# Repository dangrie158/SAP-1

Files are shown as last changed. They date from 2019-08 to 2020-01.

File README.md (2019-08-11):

# SAP-1 (Simple as Possible)

A simple 8-bit micro-processor using mostly discrete logic chips.

This project is mostly based on the [8-bit Breadboard computer](https://eater.net/8bit) by [Ben Eater](https://eater.net)

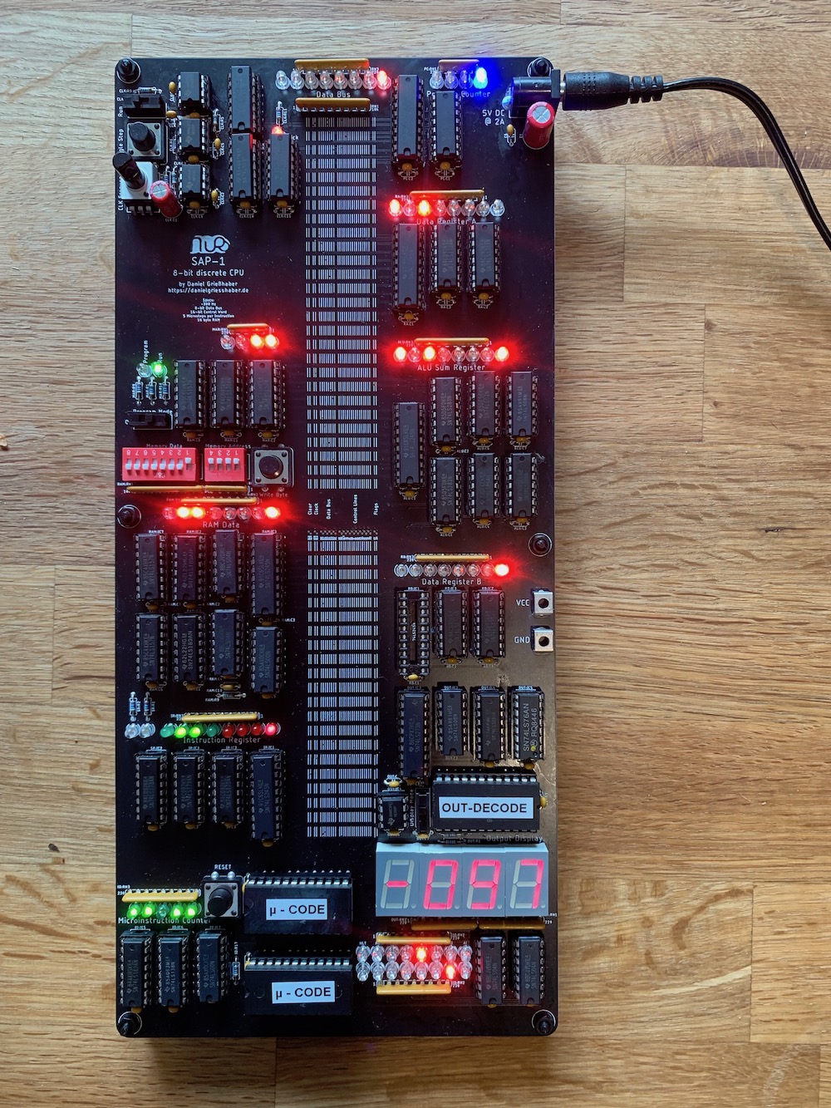
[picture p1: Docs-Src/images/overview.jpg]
Image of the Processor Board


## Banner Specs

- ~400 Hz Clock
- 8-bit Data Bus
- 16-bit Control Word
- 5 Microsteps per Instruction
- 16 byte RAM

## Documentation

Check the projects [Pages](https://dangrie158.github.io/SAP-1/) for the documentation of the ISA and Hardware modules.

## Submodules:

- Clock with adjustable frequency and single-step button
- 2 8-bit Data Registers (A & B)
- ALU implementing sum and difference between Registers A & B, carry and zero flag
- Flag Register to save the ALU flags between instructions
- 4-bit Instruction Counter with load (jump)
- Output module to display a byte as positive decimal or 2s-complement with data latch
- Random Access Memory with 16 Bytes for instructions and data
- 4-bit Memory Address Register to address the 16 bytes of RAM
- 8-bit Instruction Register with the upper nibble representing the opcode, the lower nibble can be used for instruction parameters
- Instruction Decoder to run the microcode of the 16 different instructions with 5 microinstuctions each. Uses a 16-bit control word to control the other modules

## Project Structure

| Files | Description |
|---|---|
| ```Board/Board.*``` | Autodesk Eagle project woth the Schematic and a fully routed Boardlayout |
| ```Board/Board_*.zip``` | precreated Gerbers for Production |
| ```Board/BOM.xlsx``` | a BOM with [Mouser](https://www.mouser.com) partnumbers |
| ```Spec/ISA.py``` | a Python module that defines and documents the Instruction Set Architecture of the Processor. |
| ```Spec/lut_microcode.py``` | script to create the microcode LUT binary for the ID EEPROMS. Uses ```ISA.py``` |
| ```Spec/lut_outputdecoder.py``` | script to create the LUT binary for the output decode EEPROM |
| ```LUTs/*.bin``` | precreated binaries for the EEPROMS |
| ```Example-Programs/*.s``` | Some Example Programs in SAP-1 assembly |
| ```Tools/sap-asm``` | Assembler for SAP-1 assembly listings. Outputs binaries or prints programming instructions. |
| ```Simulations/``` | [iCircuit](http://icircuitapp.com) simulation files for some parts of the architecture |

## Writing Code
The documentation has an extensive section on the [Instruction Set Architecture](https://dangrie158.github.io/SAP-1/isa.html) you can use to get started writing programs.

### Assembler:

In the ``Tools`` directory an assembler is available that can either output binary files or, if it detects stdout to be a TTY, prints programming instructions for you to manually program the RAM using the DIP-Switches.

```
$ cat Example-Programs/Counter.s 
.data:
0xF: 0x1

LDA 0xF
loop:
OUT
ADD 0xF
JMP loop

$ Tools/sap-asm Example-Programs/Counter.s
○○○○: ○○○●●●●●
○○○●: ●●●○○○○○
○○●○: ○○●○●●●●
○○●●: ○●●○○○○●
●●●●: ○○○○○○○●

$ Tools/sap-asm Example-Programs/Counter.s | hexdump 
0000000 1f e0 2f 61 00 00 00 00 00 00 00 00 00 00 00 01
0000010
```

## Programming the EEPROM LUTs

The provided ```Makefile``` offers some convenient rules to create the LUTs and program them to an EEPROM.
To program the LUTs you can use an [Arduino based programmer](https://github.com/dangrie158/EEPROgraMmer)
with only 2 external chips (+EEPROM) which is the officially supported method using the 
[```eepro```](https://pypi.org/project/eepro/) CLI. 

However, you can also use any other programmer to flash the binary files created by the scripts.

If you want to use ```eepro```, make sure the package is installed

```bash
pip3 install -r requirements.txt
```

Then you can programm the needed 3 EEPROMS (1x Output Decoder, 2x Microcode) using 

```bash
make program_lut file=LUTs/microcode.bin        # < for the microcode EEPROMS
make program_lut file=LUTs/outputdecoder.bin    # < for the Output Decoder EEPROM
```

The rule makes sure the LUTs are created or updated if the creating script has changed since last creation.

If you want to use any other programmer, just run 

```bash
make luts
```

to create the binaries in the ```LUTs/``` directory.

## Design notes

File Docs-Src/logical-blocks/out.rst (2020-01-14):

====================
Output Display (OUT)
====================
The output display can load the contents of the databus and
display it as a decimal integer on the 4x 7-segment displays.

It supports the display of either a unsigned :math:`\left[ 0, 255\right]`
or 2s-complement signed :math:`\left[ -128, 127\right]` 8-bit value.

Mode of Operation
=================
The value to display is read from the databus and saved in a
`SN74LS273 <https://www.ti.com/lit/ds/symlink/sn54ls273-sp.pdf>`_
*octal d-type flip-flop* on a riding clock edge when the
:math:`LOAD` signal is active.
Due to the lack of an enable pin on the register IC, the load signal is
implemented by ANDing the :math:`CLK` and :math:`LOAD` signal.

BCD decoder
+++++++++++
The decoding of the binary display is implemented as a lookup table (LUT)
using a `28C16 <http://cva.stanford.edu/classes/cs99s/datasheets/at28c16.pdf>`_
*2K x 8-bit parallel EEPROM*.
This IC has 11 address pins :math:`A_0-A_{10}` of which the first 8 are used to
input the display-value.
The next 2 address bits are used to select the digit of the display currently
active.
This leaves the last address pin to select the display mode (unsigned or
signed) using :math:`\mathrm{OUT\colon S_3}`.

Digit multiplexing
++++++++++++++++++
Since the EEPROM decoder can only drive a single digit at any time with it's 8
output lines, the 4 digits need to be multiplexed.
This is done by sequentially driving the common-cathode pin of each digit low
while simultaneously setting the :math:`A_8` and :math:`A_9` address pins of
the EEPROM which in turn will drive the anodes of the selected display digit
to the apropriate value.

The binary digit select signal that drives the address lines is implemented
by a single `SN74LS76 <http://www.ti.com/lit/ds/symlink/sn54ls76a.pdf>`_
*dual J-K flip flop* IC to implement a 2 bit binary counter.
This counter is driven by an astable `LM555 <http://www.ti.com/lit/gpn/lm555>`_
oscillator that runs fast enough to cycle through the digits without
perceivable flickering:

.. math::

   {f}_{out} &= \frac{1.44}{\mathrm{OUT\colon R_1} + 2* \mathrm{OUT\colon R3}) * \mathrm{OUT\colon C_7}} \\
   {f}_{out} &= \frac{1.44}{201kΩ * 10nF} \\
   {f}_{out} &= ~716Hz

.. math::

   {f}_{multiplex} &= \frac{{f}_{out}}{4} \\
   {f}_{multiplex} &= ~179Hz

The bianry coded digit select signal is then decoded using a
`SN74LS139 <http://www.ti.com/lit/ds/symlink/sn54ls139a-sp.pdf>`_
*2-line to 4-line decoder with active low outputs* to drive the cathodes.

LED Output Drive
++++++++++++++++
According to the `datasheet <http://cva.stanford.edu/classes/cs99s/datasheets/at28c16.pdf>`_
of the decoder EEPROM, the chip can drive :math:`10-20mA` with a
:math:`0.5 - 1.5V` drop in its output voltage.
This may be too big of a drop when combined with the :math:`220Ω` series
resistors when used for higher voltage drop LED displays (like blue or white).
If you have trouble with the output display being too dim or not lighting
up at all, replace the resistor networks :math:`\mathrm{RN}_1`
and :math:`\mathrm{RN}_2` with jumpers or choose a lower resistance network.

Schematic
=========
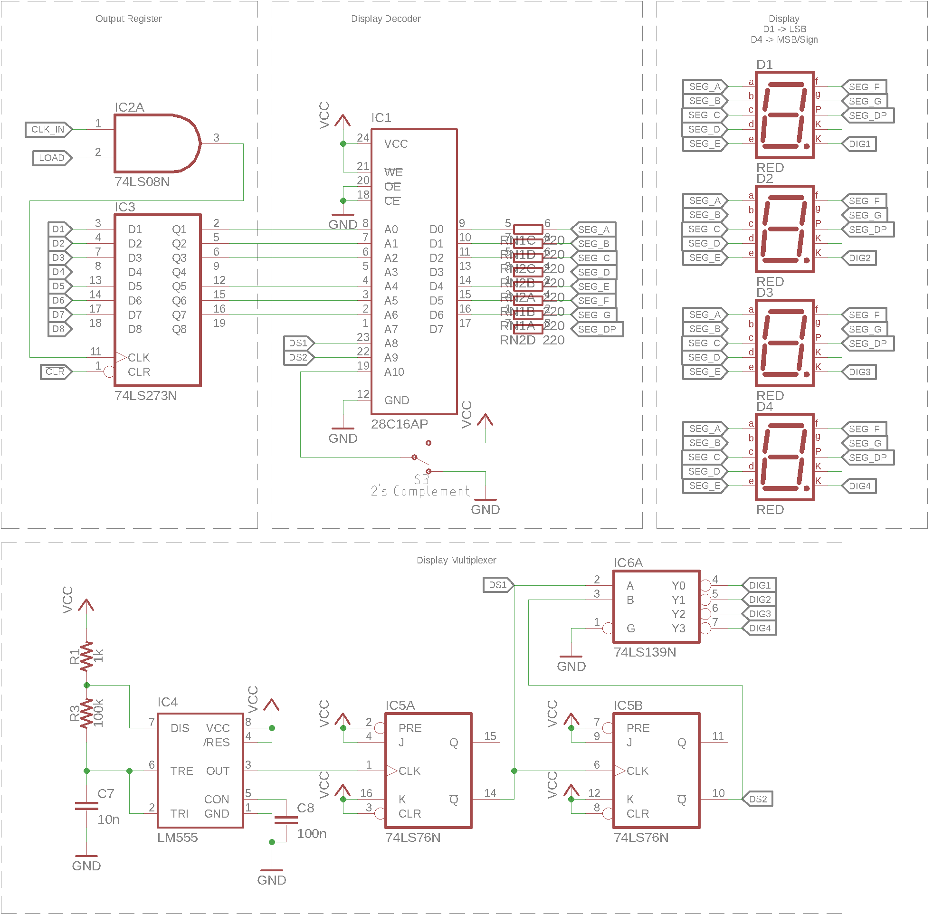
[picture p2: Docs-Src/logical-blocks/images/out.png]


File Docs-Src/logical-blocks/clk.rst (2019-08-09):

===========
Clock (CLK)
===========
The clock module is responsible for all time related coordination
between the seperate modules.

Mode of Operation
=================
The module has 2 outputs that feed into the other modules,
the **positive clock line** (:math:`CLK`) and its
**logical inverse** (:math:`\overline{CLK}`).
The :math:`\overline{CLK}` signal is always low when the clock signal is
high and vice-versa, this way the processor has 2 clock signals that are
on a 180° phase difference.

The source for the clock pulses is selectable via the **Source Select**
switch and can either be set to *run* mode or *single-step*.

*Run* mode
----------
In *run* mode, the clock signal is created by a 555 timer in astable
configuration. The dutycycle of the signal is 50%, while the frequency
can be set using a potentiometer.
The clock frequency is set by :math:`\mathrm{CLK\colon R_1}`,
:math:`\mathrm{CLK\colon R_2} + \mathrm{CLK\colon RV_2}` and
:math:`\mathrm{CLK\colon C_1}`:

.. math::

   {f}_{clk} &= \frac{1.44}{( \mathrm{CLK\colon R_1} + 2 * (\mathrm{CLK\colon R_2} + \mathrm{CLK\colon RV_2}) ) * \mathrm{CLK\colon C_1}} \\
   {f}_{clk} &= \frac{1.44}{( 1kΩ + 2*(1kΩ + [0, 100kΩ]) ) * 1µF} \\
   {f}_{clk} &= [480.0Hz, ~7.1Hz]

*Single-step* mode
------------------
In *single-step* mode, the positive clock signal is set by pressing the
**Single Step** button and cleared after releasing it.
Another 555 timer in monostable configuration is used to debounce
the button presses to avoid accidentaly creating multiple steps on a
single press.
The debounce time is set by the RC network consisting of
:math:`\mathrm{CLK\colon R_6}` and :math:`\mathrm{CLK\colon C_5}` and can be
calculated as:

.. math::

   T_o &= 1.1 * \mathrm{CLK\colon R_6} * \mathrm{CLK\colon C_5} \\
   T_o &= 1.1 * 100nF * 1kΩ \\
   T_o &= 110µS

Clock Source selection & Halt signal
------------------------------------
The actual output signal is a logical combination of the two 555 timer
outputs and the output of a third 555 in bistable mode.
This third 555 is used to debounce the signal of a single-pole
double-throw (SPDT) slide-switch.
The debouncing is neccessary because otherwise a switch bounce could
generate multiple clock ticks when switching modes while the 2 clock
signals have a different state.

In any way, a clock pulse is only output if the
**halt signal** (:math:`CLK_{HLT}`) is inactive.
This halt signal is part of the **control word (CW)** and can be used to
stop program execution.

.. math:: \mathrm{CLK} = \neg CLK_{HLT} \land ((\mathrm{CLK_{TICK}} \land \mathrm{CLK_{SEL}}) \lor (CLK_{STEP} \land \neg CLK_{SEL}))

Schematic
=================
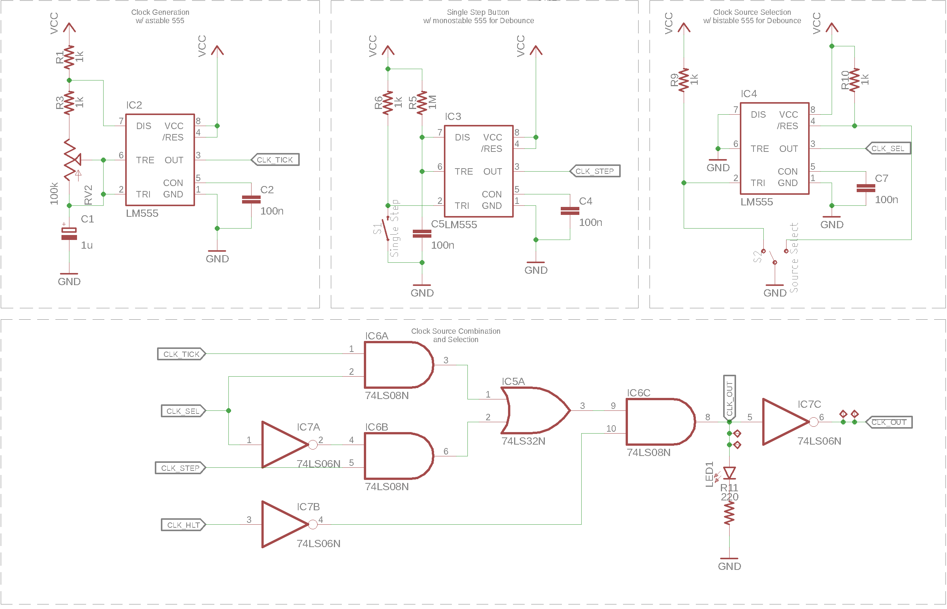
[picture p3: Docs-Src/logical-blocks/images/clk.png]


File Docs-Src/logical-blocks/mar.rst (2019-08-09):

=============================
Memory Address Register (MAR)
=============================
The memory address register stores the address of the data
the `RAM <ram.html>`_ module should be pointing at.

Mode of Operation
=================
The memory address register is very similar in its operation
principle to any of the `data registers <datareg.html>`_.

It uses the same `74LS173 <http://www.ti.com/lit/ds/symlink/sn54173.pdf>`_
*4-bit D-type registers*, however since it's output is not connected
to the databus but instead directly to the address pins of the RAM module,
no buffers are used at the output.

Instead a `74LS157 <http://www.ti.com/lit/ds/symlink/sn54157.pdf>`_
*quadruple 2-to-1 multiplexer* is used to select either the
register contents or a DIP switch array to set the address outputs.
The DIP switches can be used in **program mode** to set the address manually
while in **run mode** the address can be loaded as the lower 4 bits
of the data bus which represent the instruction data (ID) nibble of
an instruction (see the `ISA <../isa.html>`_ section for more detail).

To select the current mode of operation (run / program), the SPDT switch
**Program / Run** can be used.

Schematic
=========
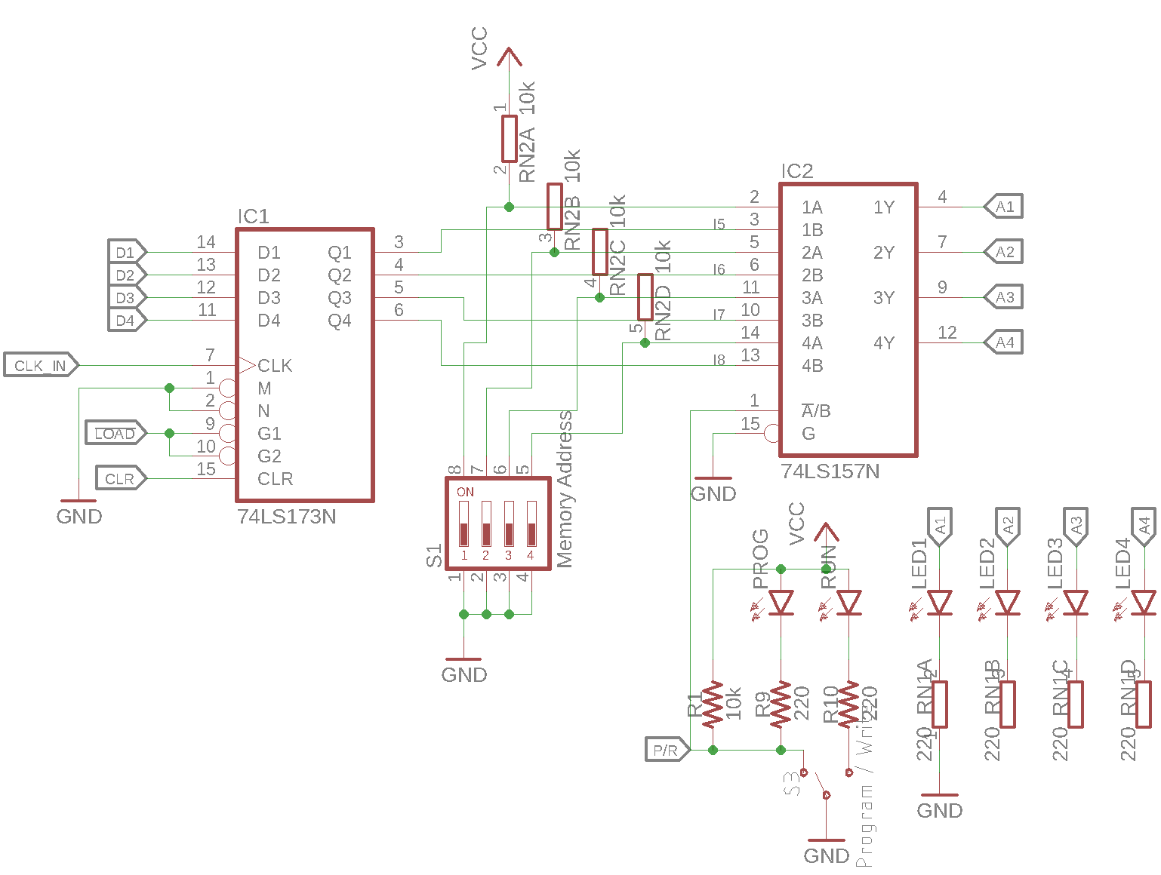
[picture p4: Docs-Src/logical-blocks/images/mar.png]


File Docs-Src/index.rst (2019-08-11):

.. SAP-1 Processor Architecture documentation master file, created by
   sphinx-quickstart on Wed Aug  7 08:08:43 2019.
   You can adapt this file completely to your liking, but it should at least
   contain the root `toctree` directive.

============================
SAP-1 Processor Architecture
============================

A simple 8-bit micro-processor using mostly discrete logic chips.

This project is mostly based on the `8-bit Breadboard computer <https://eater.net/8bit>`_
by `Ben Eater <https://eater.net>`_



   Overview of the assembled processor board running `Example-Programs/Counter.s`

Banner Specs
============

- ~400 Hz Clock
- 8-bit Data Bus
- 16-bit Control Word
- 5 Microsteps per Instruction
- 16 byte RAM

Source (I want to build my own)
===============================
Check the projects `Github <https://github.com/dangrie158/SAP-1/>`_ for all files neccecary.

Submodules
==========
- Clock with adjustable frequency and single-step button
- 2 8-bit Data Registers (A & B)
- ALU implementing sum and difference between Registers A & B,
    carry and zero flag
- Flag Register to save the ALU flags between instructions
- 4-bit Instruction Counter with load (jump)
- Output module to display a byte as positive decimal or
    2s-complement with data latch
- Random Access Memory with 16 Bytes for instructions and data
- 4-bit Memory Address Register to address the 16 bytes of RAM
- 8-bit Instruction Register with the upper nibble representing
    the opcode, the lower nibble can be used for instruction parameters
- Instruction Decoder to run the microcode of the 16 different instructions
    with 5 microinstuctions each. Uses a 16-bit control word to control the
    other modules

Writing Code
============
The documentation has an extensive section on the
`Instruction Set Architecture <https://dangrie158.github.io/SAP-1/isa.html>`_
you can use to get started writing programs.

Assembler
++++++++++
In the ``Tools`` directory an assembler is available that can
either output binary files or, if it detects stdout to be a TTY,
prints programming instructions for you to manually program the RAM
using the DIP-Switches.

.. code:: bash

    $ cat Example-Programs/Counter.s
    .data:
    0xF: 0x1

    LDA 0xF
    loop:
    OUT
    ADD 0xF
    JMP loop

    $ Tools/sap-asm Example-Programs/Counter.s
    ○○○○: ○○○●●●●●
    ○○○●: ●●●○○○○○
    ○○●○: ○○●○●●●●
    ○○●●: ○●●○○○○●
    ●●●●: ○○○○○○○●

    $ Tools/sap-asm Example-Programs/Counter.s | hexdump
    0000000 1f e0 2f 61 00 00 00 00 00 00 00 00 00 00 00 01
    0000010

Programming the EEPROM LUTs
===========================

The provided ``Makefile`` offers some convenient rules to
create the LUTs and program them to an EEPROM.
To program the LUTs you can use an
`Arduino based programmer <https://github.com/dangrie158/EEPROgraMmer>`_
with only 2 external chips (+EEPROM) which is the officially
supported method using the `eepro <https://pypi.org/project/eepro/>`_
CLI.

However, you can also use any other programmer to flash
the binary files created by the scripts.

If you want to use ``eepro``, make sure the package is installed

.. code:: bash

    pip3 install -r requirements.txt

Then you can programm the needed 3 EEPROMS (1x Output Decoder,
2x Microcode) using:

.. code:: bash

    make program_lut file=LUTs/microcode.bin     # < for the microcode EEPROMS
    make program_lut file=LUTs/outputdecoder.bin # < for the Out Decoder EEPROM

The rule makes sure the LUTs are created or updated if
the creating script has changed since last creation.

If you want to use any other programmer, just run

.. code:: bash

    make luts

to create the binaries in the ``LUTs/`` directory.

.. toctree::
   :maxdepth: 3
   :caption: Contents:

   isa
   block-diagram

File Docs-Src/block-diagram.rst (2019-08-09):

===============
Hardware Blocks
===============
The SAP-1 Processor can logically be grouped into the following
submodules.

.. toctree::
   :maxdepth: 1

   logical-blocks/clk
   Data Register A <logical-blocks/datareg>
   Data Register B <logical-blocks/datareg>
   Instruction Register <logical-blocks/datareg>
   logical-blocks/alu
   logical-blocks/ram
   logical-blocks/mar
   logical-blocks/pc
   logical-blocks/out
   logical-blocks/id
   logical-blocks/sr

The individual modules communicate over the 8-bit Data Bus and
are controlled by the control lines in the Control Word.
Other than that, the only shared signals between modules are the
global clock (CLK and its inverse !CLK), and the clear signal (CLR and !CLR).

The block diagram shows how the modules are connected together.
The 8-bit bus in the middle is the databus, while the blue line
on the outside is the control word with 16 control lines.

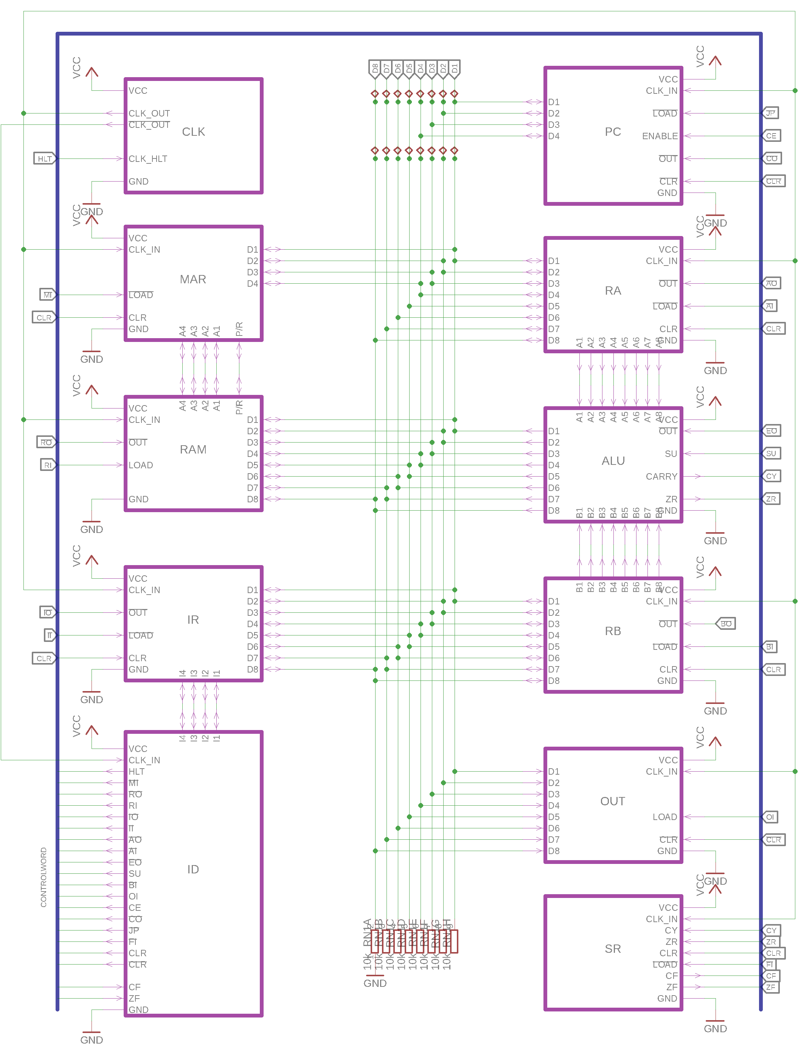
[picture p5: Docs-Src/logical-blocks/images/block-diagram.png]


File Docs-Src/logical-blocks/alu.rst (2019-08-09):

===========================
Arithmetic Logic Unit (ALU)
===========================
The ALU enables the Processor to perform simple arithmetic operations.
In fact, it only can perform the addition or substraction of the values
in the two data registers RA and RB:

.. math::
   \mathrm{ALU_{OUT}} &= \mathrm{RA} + \mathrm{RB} \quad \mathrm{or}\\
   \mathrm{ALU_{OUT}} &= \mathrm{RA} - \mathrm{RB}

Mode of Operation
=================

Addition
--------
The ALU uses 2 `74LS283 <http://www.ti.com/lit/ds/symlink/sn74ls283.pdf>`_
*4-bit binary adders with carry*.
The **carry output** (:math:`\mathrm{ALU\colon C_4}`) of
:math:`\mathrm{ALU\colon IC_1}` is connected to the **carry input**
(:math:`\mathrm{ALU\colon C_0}`) of :math:`\mathrm{ALU\colon IC_2}`,
thus a carry after bit 4 is propagated to the second nibble of the result.
The inputs A and B of the ICs are connected directly to the outputs
of the 74LS173 registers of RA and (through XOR gates) RB instead of
the DB.
For addition, the **substract line** :math:`\mathrm{SU}` line is low, thus
the XOR gates output the same value as the input from RB.
To only drive the DB lines when the result of the computation is needed,
another 74LS245 is used as tristate buffer, enabling the display of the
result on :math:`\mathrm{ALU\colon LED_{1-8}}` without driving the DB.

Substraction
------------
For substraction of RA and RB, the :math:`\mathrm{SU}` signal is active,
thus the output of the XOR gates is always the *logical inverse* of the input
from RB.
Thus the second byte into the 8-bit adder is the *1s complement* of RB.
To calculate a `2s complement <https://en.wikipedia.org/wiki/Two%27s_complement>`_
result however, the :math:`\mathrm{SU}` signal also drives the
:math:`\mathrm{ALU\colon C_0}` input of :math:`\mathrm{ALU\colon IC_1}`,
effectivley adding 1 to the result.

Flags
-----
The *carry signal* :math:`\mathrm{CY}` can be read directly from the
:math:`\mathrm{ALU\colon C_4}` pin of the second nibble adder
:math:`\mathrm{ALU\colon IC_2}`.

For the zero flag signal :math:`\mathrm{ZR}`, all output bits are NORed
together.
Since there are no 8-input NOR gates available (at least in the commonly
available 74LS series logic family), a quad 2-input NOR gate
(`74LS02 <http://www.ti.com/lit/ds/symlink/sn74ls02.pdf>`_) is used to
NOR every 2 bits together, then each of the outputs is ANDed together using
a quad 2-input AND gate (`74LS02 <http://www.ti.com/lit/ds/symlink/sn74ls02.pdf>`_)
until only a single signal is left that will be active high when all ALU
output bits are cleared.

Schematic
=========
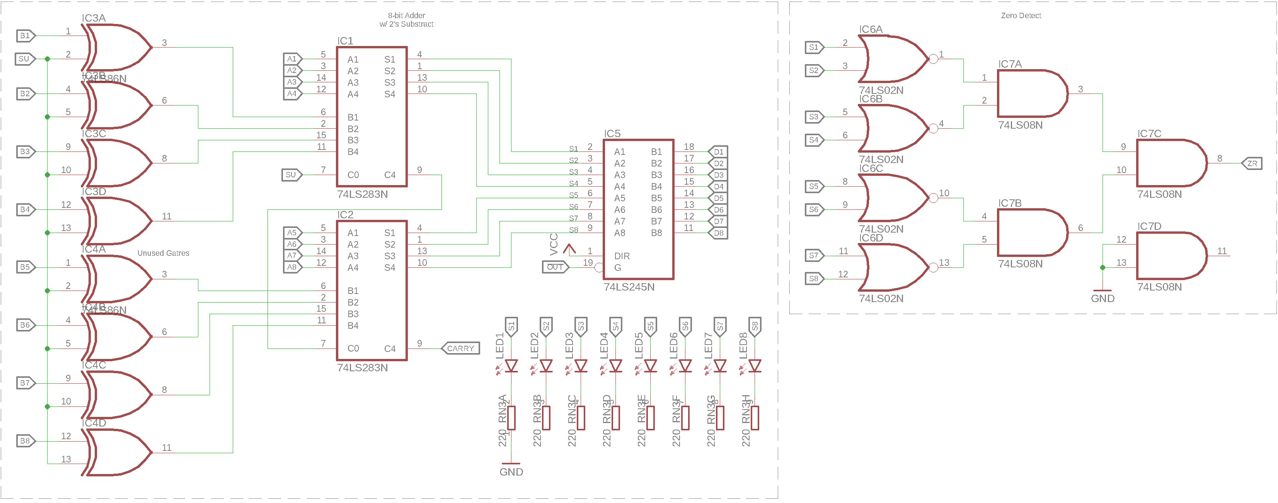
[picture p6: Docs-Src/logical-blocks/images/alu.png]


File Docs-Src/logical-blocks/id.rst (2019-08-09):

========================
Instruction Decoder (ID)
========================
The instruction decoders job is to generate the control word (CW) which
consists of the control lines of the other modules thus controlling the
behaviour of the processor and all its submodules.
The control word is created based on the current instruction, the
microinstruction in this instruction and the state of the processors flags.

Mode of Operation
=================

The instrcution decoder uses 2
`28C16 <http://cva.stanford.edu/classes/cs99s/datasheets/at28c16.pdf>`_
*2K x 8-bit parallel EEPROMs* to decode the combination of the 4 instruction
bits :math:`\mathrm{I_1} - \mathrm{I_4}`, the micro instruction counter
:math:`\mathrm{MI_1} - \mathrm{MI_3}` and the flags :math:`\mathrm{CF}` and
:math:`\mathrm{ZF}` to a 16-bit control word.
The address line :math:`\mathrm{A_7}` is pulled low for :math:`\mathrm{IC_1}`
while tied to VCC for :math:`\mathrm{IC_2}`.
This way it is possible to flash both EEPROMs with the same lookup table for
instruction decoding.

CW Lookup Table
+++++++++++++++
The control word for each microinstruction for all instructions is described in
the `instruction set architecture <../isa.html>`_.

Microinstruction Counter
++++++++++++++++++++++++
The current microinstruction step is counted by a
`SN74LS161 <http://www.ti.com/lit/ds/symlink/sn74ls161a.pdf>`_
*4-bit syncronous counter* of which only 3 bits are used to count the 5
possible number of microsteps.
The outputs :math:`\mathrm{Q_A} - \mathrm{Q_C}` of the counter are decoded
using a `SN74LS138 <http://www.ti.com/lit/ds/symlink/sn74ls138.pdf>`_
*3-line to 8-line* decoder.
The output of the 6th decoded line is fed through a dual NAND gate to form
an OR gate with inverted inputs.
Thus the counter will be reset to zero, immediately after reaching the value 6,
effectivley counting 0-5.
The second input to the first NOR gate implements a active-low reset signal
for the counter connected to the reset circuit.

Active High Control Word
++++++++++++++++++++++++
Some lines in the CW are active-low.
To normalize the behaviour of all control lines, to active high, the 2
inverters :math:`\mathrm{ID\colon IC_3}` and :math:`\mathrm{ID\colon IC_4}`
are used to flip the polarity of the active low signals before outputting.
This makes programming of the instruction decoder easier.

System Reset
++++++++++++
The control word module also contains the reset circuit which controls the
:math:`\mathrm{CLR}` signal and it's logical inverse
:math:`\overline{\mathrm{CLR}}` that is used for modules with an active-low
clear line.

To buffer the signal of the reset button and invert it's state, the 2 remaining
NAND gates of the microinstruction counter are used.

Schematic
=========
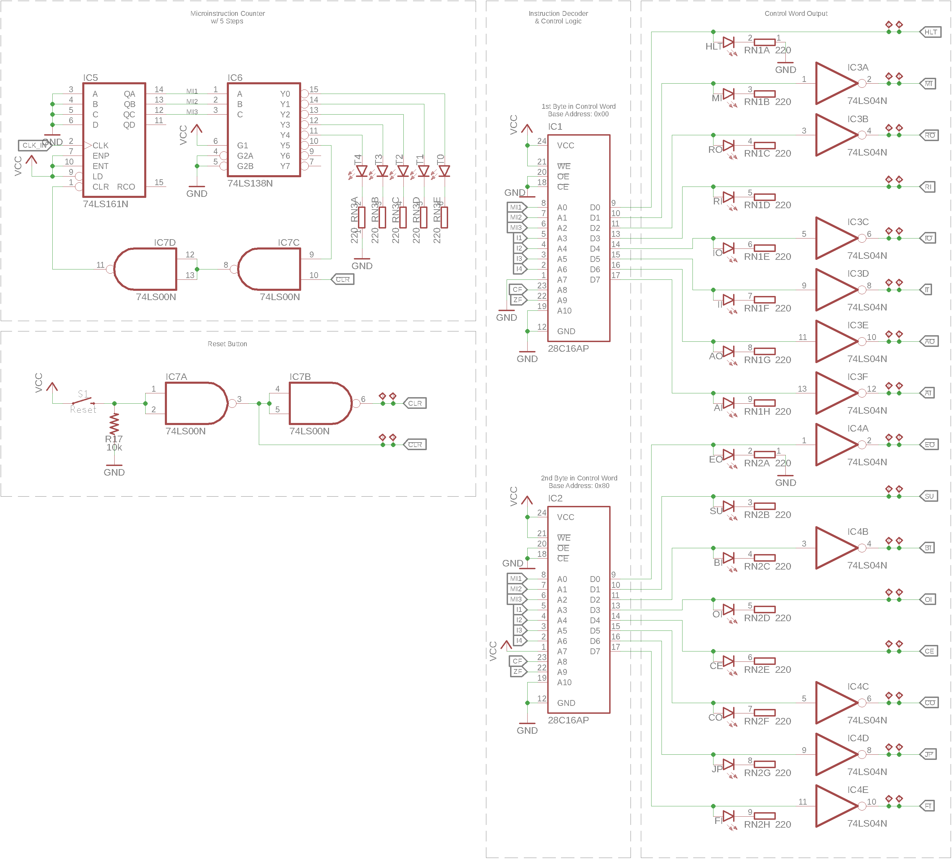
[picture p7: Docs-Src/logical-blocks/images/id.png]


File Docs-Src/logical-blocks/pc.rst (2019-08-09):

====================
Program Counter (PC)
====================
The program counter contains the RAM address of the next instruction to
execute.

Mode of Operation
=================
The PC is 0-initialized, thus the first instruction executed after a reset
is always at RAM byte 0.
For the counter, a `SN74LS161 <http://www.ti.com/lit/ds/symlink/sn74ls161a.pdf>`_
*4-bit syncronous counter* IC is used.

Count increment
+++++++++++++++
The counter will increment it's value whenever a clock pulse occurs while the
:math:`\mathrm{{ENABLE}` line is active.
This normally happens as the second microinsruction in a FETCH cycle as
described in the `ISA <../isa.html>`_ section.

Count Set
+++++++++
The current value can be loaded from the databus by enabling the
active-low :math:`\mathrm{\overline{LOAD}}` line which sets the counter
to the lower nibble of the databus on the next clock cycle.
This can be used to set the address of the next instruction and thus
implementing a JUMP instruction.

To enable writing the current counter's value to the DB, another
`74LS245 <http://www.ti.com/lit/ds/symlink/sn54ls245-sp.pdf>`_
*Octal Bus Tranciever* is used as a buffer.

Schematic
=========
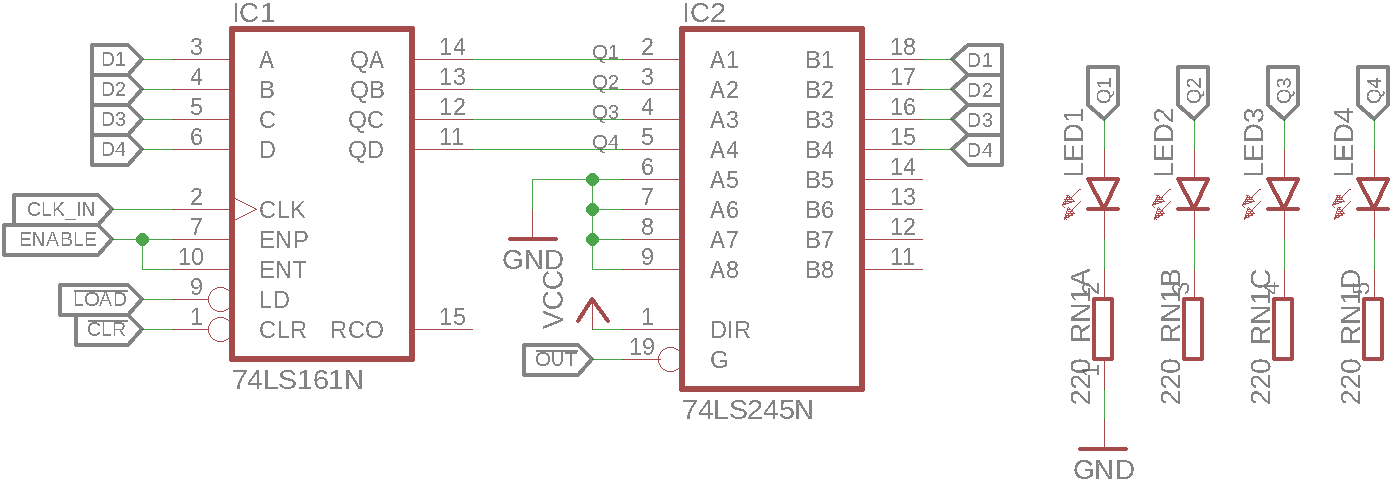
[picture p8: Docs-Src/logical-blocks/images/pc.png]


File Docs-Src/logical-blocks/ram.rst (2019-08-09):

==========================
Random Access Memory (RAM)
==========================
The RAM module allows to store up to **16 bytes** of arbitrary data
and access it by addressing the byte number in any order (random) rather
that only one after the other (sequential).

The SAP-1 implements a
`von Neumann architecture <https://en.wikipedia.org/wiki/Von_Neumann_architecture>`_
which means there is only a single memory for instructions and data, thus
both, the program and all data neccecary need to be stored in the
16 bytes of RAM.

Mode of Operation
=================
The actual RAM storage is implemented using 2 seperate
`74LS189 <http://ltodi.est.ips.pt/lab-dee-et/datasheets/TTL/74189.pdf>`_
*64 bit RAM with tristate output* ICs (:math:`\mathrm{RAM\colon IC_1}` and
:math:`\mathrm{RAM\colon IC_2}`) which are organized as :math:`16 x 4`
bit, thus each IC will be responsible for one nibble of the data byte.

For whatever reason, the 74LS189 chips have an inverted output, thus 2
additional `SN74LS04 <http://www.ti.com/lit/ds/symlink/sn74ls04.pdf>`_
*hex inverters* (:math:`\mathrm{RAM\colon IC_4}` and
:math:`\mathrm{RAM\colon IC_5}`) are used to flip the logic of the
output again.

To be able to visualise the RAM contents at any address without needing
to drive the databus, the same
`74LS245 <http://www.ti.com/lit/ds/symlink/sn54ls245-sp.pdf>`_ buffer
that is used in the `data registers <datareg.html>`_ is inserted between
the RAM IC outputs and the databus lines.

The RAM Module needs to support 2 modes of operation which are selected
by the :math:`P/R` signal which is generated by the
`Memory Address Register <mar.html>`_ module.

Program Mode
++++++++++++
In **program** mode, bytes of data can be written to RAM by setting DIP
switches representing the 8-bit value.

The program mode is selected by clearing the :math:`P/R` signal which
setups the 3 `74LS157 <http://www.ti.com/lit/ds/symlink/sn54157.pdf>`_
*quadruple 2-to-1 multiplexers* (:math:`\mathrm{RAM\colon IC_{6-8}}`)
to select the A inputs and replicate their states on it's outputs.

:math:`\mathrm{RAM\colon IC_{8}}` is only used to select a single data-line
which is connected to the :math:`\overline{WE}` (write enable, active low)
pins of the register ICs.
Input 1A of this IC is connected to the tactile button **Write Byte** that
pulls the line low when pressed, thus writing the current inputs to the
selected RAM address.
The button presses are not debounced, since multiple writes of the same value
to the same address do not cause unwanted side-effects.

Run Mode
++++++++
In **run** mode, the module read or write the databyte addressed by the
**Memory Address Register (MAR)** to the **databus (DB)**.

In run mode, the :math:`P/R` signal is driven high, thus selecting the
B inputs of the multiplexers.
For :math:`\mathrm{RAM\colon IC_{6}}` and :math:`\mathrm{RAM\colon IC_{7}}`,
the B inputs are connected to the databus, thus pulling the
:math:`\overline{\mathrm{WE}}` line low in run mode will write the current
byte on the DB into the selected RAM address.

The write line is set by NANDing the the  :math:`\mathrm{LOAD}` and
:math:`\mathrm{CLK}` signal thus the byte is written on a clock-edge and an
active :math:`\mathrm{LOAD}` signal.

To only write the byte on the rising edge of the clock signal, the signal is
filtered by the `RC high-pass <https://en.wikipedia.org/wiki/High-pass_filter>`_
built by :math:`\mathrm{RAM\colon C_{10}}` and
:math:`\mathrm{RAM\colon R_9}`.
This is neccesary to avoid writing the state at the very end of the clock
signal which could cause a race condition with whatever module is setting the
DB state.

Schematic
=========
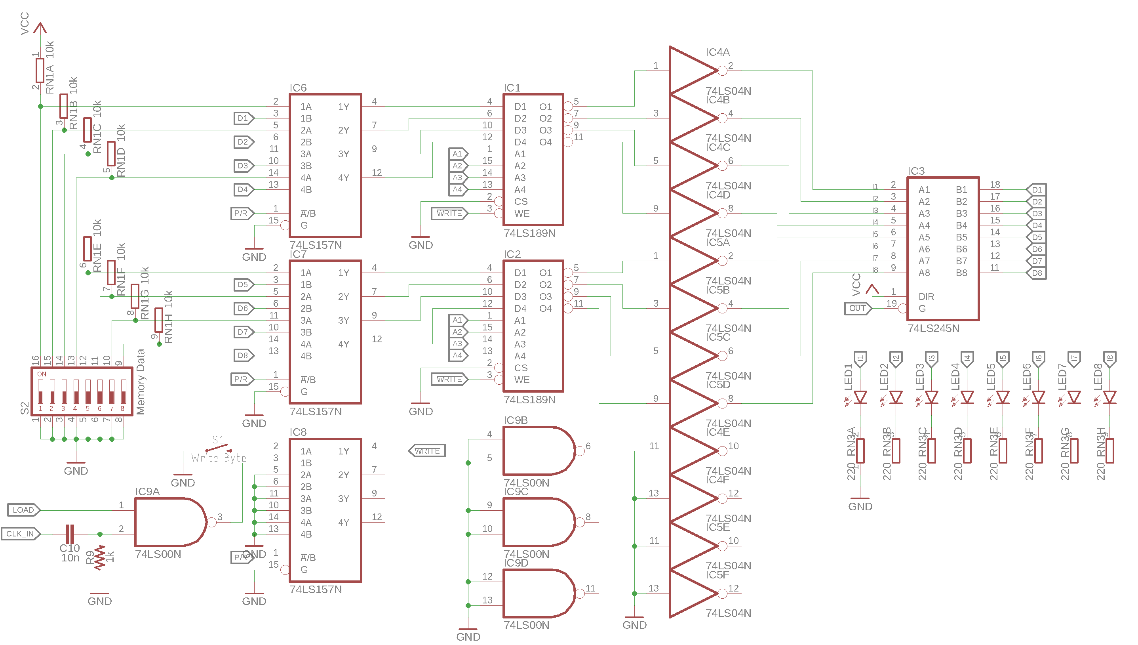
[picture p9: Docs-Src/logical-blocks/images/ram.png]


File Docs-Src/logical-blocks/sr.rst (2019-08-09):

====================
Status Register (SR)
====================
The status registers job is to buffer the state of of the carry
(:math:`\mathrm{CY}`) and zero (:math:`\mathrm{ZR}`) flags of the ALU
across microinstructions.
This is neccessary as the result of any ALU computation is stored in
register A and since the ALU uses the unbuffered outputs from the
registers, writing back the result and thus changing the registers content
may change the flags.
Thus, the flags need to be saved before writing back the result of any ALU
computation to Register A.

Mode of Operation
=================
The SR may be the simplest register in the system. It only uses 2 out of
the 4 bits available in a single `74LS173 <http://www.ti.com/lit/ds/symlink/sn54173.pdf>`_
*4-bit D-type register* IC.
As the register is not connected to the databus but instead to the
`instruction decoder <id.html>`_, the outputs are unbuffered.

Schematic
=========
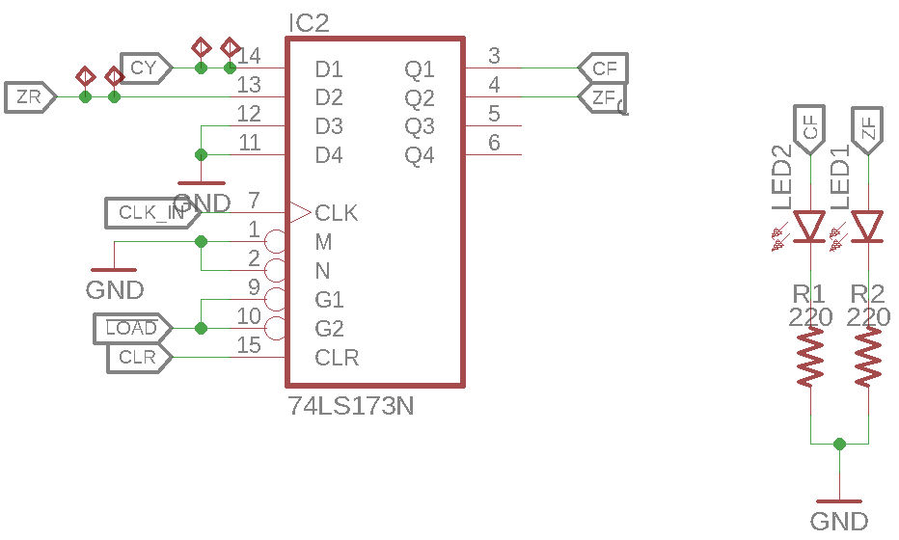
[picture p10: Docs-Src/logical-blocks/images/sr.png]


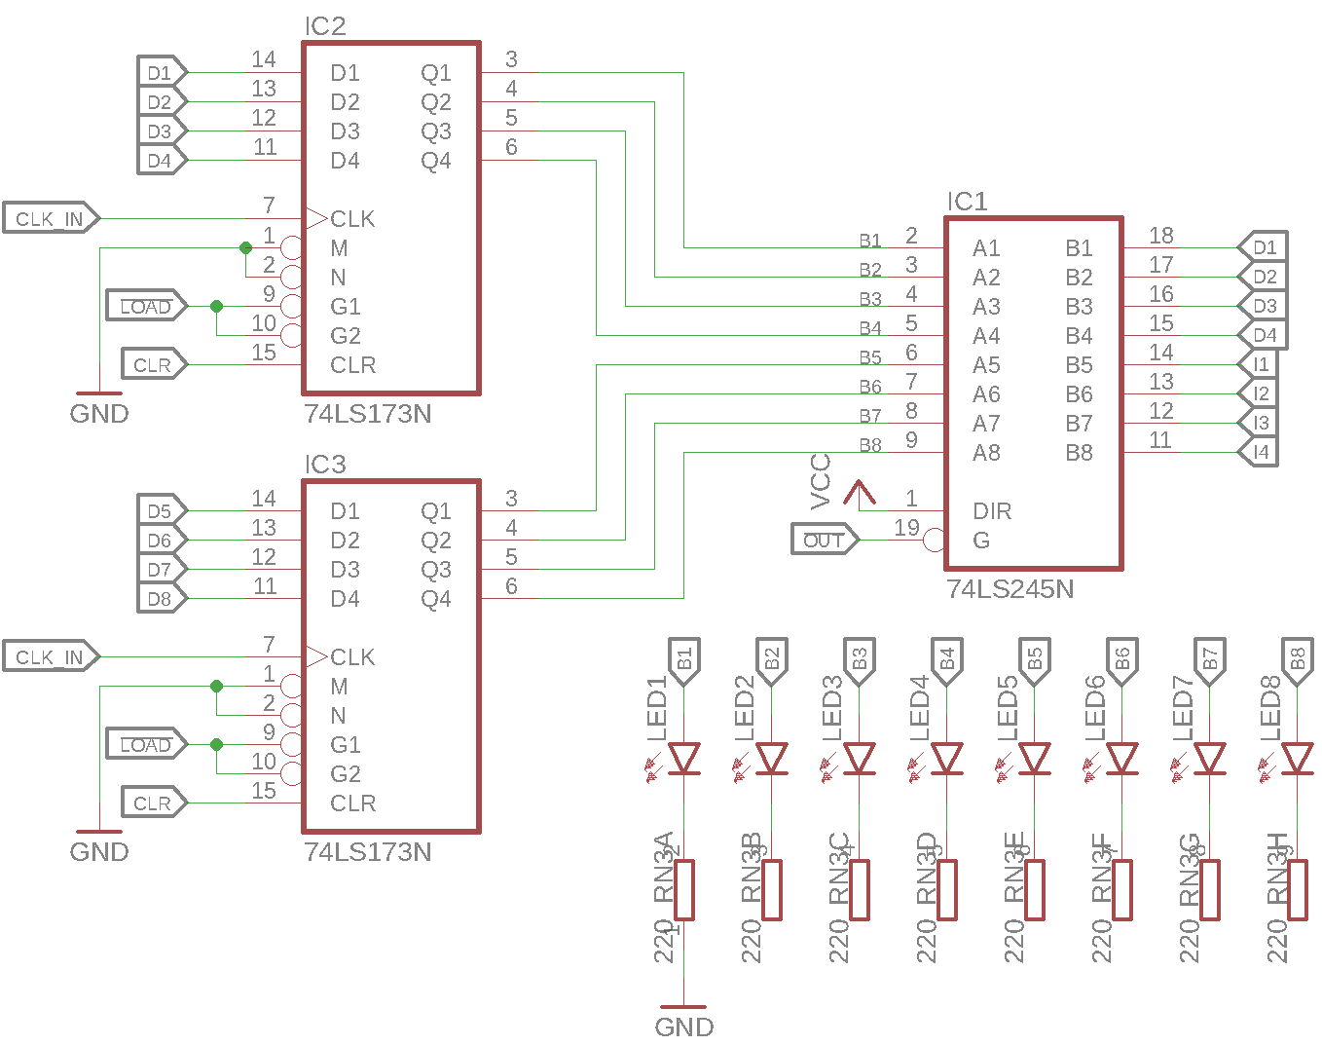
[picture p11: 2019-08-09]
docs/_images/ir.png

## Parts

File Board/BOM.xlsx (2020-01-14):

Qty | Value | Device | Package | Parts | Description | MOUSER
1 | 100k | POTALPS-KIT | ALPS_POT_KIT | CLK:RV2 |  | PTV09A-4020F-B105
1 | 100k | R-US_0204/7 | 0204/7 | OUT:R3 | RESISTOR, American symbol | 594-5063JD100K0F
55 | 100n | C-EU050-024X044 | C050-024X044 | ALU:C1, ALU:C2, ALU:C3, ALU:C4, ALU:C5, ALU:C6, ALU:C7, C6, CLK:C2, CLK:C3, CLK:C4, CLK:C5, CLK:C6, CLK:C7, CLK:C8, CLK:C9, CLK:C10, CLK:C11, ID:C1, ID:C2, ID:C3, ID:C4, ID:C5, ID:C6, ID:C7, IR:C1, IR:C2, IR:C3, MAR:C1, MAR:C2, OUT:C1, OUT:C2, OUT:C3, OUT:C4, OUT:C5, OUT:C6, OUT:C8, PC:C1, PC:C2, RA:C1, RA:C2, RA:C3, RAM:C1, RAM:C2, RAM:C3, RAM:C4, RAM:C5, RAM:C6, RAM:C7, RAM:C8, RAM:C9, RB:C1, RB:C2, RB:C3, SR:C1 | CAPACITOR, European symbol | 594-K104K15X7RF53H5
1 | 100u | CPOL-EUE3.5-8 | E3,5-8 | C1 | POLARIZED CAPACITOR, European symbol | 710-860040674004
1 | 10k | GE04R | SIL5 | MAR:RN2 | SIL RESISTOR | 652-4605X-1LF-10K
2 | 10k | GE08R | SIL9 | RAM:RN1, RN1 | SIL RESISTOR | 652-4609X-1LF-10K
1 | 10k | R-US_0204/7 | 0204/7 | ID:R17 | RESISTOR, American symbol | 594-5063JD10K00F
1 | 10k | R-US_0204/7 | 0204/7 | MAR:R1 | RESISTOR, American symbol | 594-5063JD220R0F
2 | 10n | C-EU050-024X044 | C050-024X044 | OUT:C7, RAM:C10 | CAPACITOR, European symbol | 594-K103K15X7RF5TH5
1 | 1M | R-US_0204/7 | 0204/7 | CLK:R5 | RESISTOR, American symbol | 594-5063JD1M000F
7 | 1k | R-US_0204/7 | 0204/7 | CLK:R1, CLK:R3, CLK:R6, CLK:R9, CLK:R10, OUT:R1, RAM:R9 | RESISTOR, American symbol | 594-5063JD1K000F
1 | 1u | CPOL-EUE2.5-7 | E2,5-7 | CLK:C1 | POLARIZED CAPACITOR, European symbol | 710-860021373002
1 | 2's Complement | SWITCH-SPDT-PTH-11.6X4.0MM-KIT | SWITCH_SPDT_PTH_11.6X4.0MM_KIT | OUT:S3 | Single Pole, Double Throw (SPDT) Switch | 474-COM-00102
2 | 220 | E4R | SIL8 | OUT:RN1, OUT:RN2 | SIL RESISTOR | 652-4608X-2LF-220
2 | 220 | GE04R | SIL5 | MAR:RN1, PC:RN1 | SIL RESISTOR | 652-4605X-1LF-220
9 | 220 | GE08R | SIL9 | ALU:RN3, ID:RN1, ID:RN2, ID:RN3, IR:RN3, RA:RN3, RAM:RN3, RB:RN3, RN3 | SIL RESISTOR | 652-4609X-1LF-220
5 | 220 | R-US_0204/7 | 0204/7 | CLK:R11, MAR:R9, MAR:R10, SR:R1, SR:R2 | RESISTOR, American symbol | 594-5063JD220R0F
3 | 28C16AP | 28C16AP | DIL24-6 | ID:IC1, ID:IC2, OUT:IC1 | CMOS EPROM 16 K (2 K x 8)
2 | 2019-02-03 | MOUNT-PAD-ROUND3.2 | 3,2-PAD | H5, H6 | MOUNTING PAD, round
2 | 74LS00N | 74ALS00N | DIL14 | ID:IC7, RAM:IC9 | Quad 2-input NAND gate | 595-SN74LS00N
1 | 74LS02N | 74LS02N | DIL14 | ALU:IC6 | Quad 2-input NOR gate | 595-SN74LS02N
5 | 74LS04N | 74LS04N | DIL14 | CLK:IC7, ID:IC3, ID:IC4, RAM:IC4, RAM:IC5 | Hex INVERTER | 595-SN74LS06N
3 | 74LS08N | 74ALS08N | DIL14 | ALU:IC7, CLK:IC6, OUT:IC2 | Quad 2-input AND gate | 595-SN74LS08N
1 | 74LS138N | 74LS138N | DIL16 | ID:IC6 | 3-line to 8-line DECODER/DEMULTIPLEXER | 595-SN74LS138N
1 | 74LS139N | 74LS139N | DIL16 | OUT:IC6 | Dual 2-line to 4-line DECODER/DEMULTIPLEXER | 595-SN74LS139AN
4 | 74LS157N | 74LS157N | DIL16 | MAR:IC2, RAM:IC6, RAM:IC7, RAM:IC8 | Quadruple 2-line to 1-line data SELECTOR/MULTIPLEXER | 595-SN74LS157N
2 | 74LS161N | 74160N | DIL16 | ID:IC5, PC:IC1 | Synchronous 4-bit COUNTER | 595-SN74LS161AN
8 | 74LS173N | 74LS173N | DIL16 | IR:IC2, IR:IC3, MAR:IC1, RA:IC2, RA:IC3, RB:IC2, RB:IC3, SR:IC2 | 4-bit D type REGISTER, 3-state | SN74LS173AN
2 | 74LS189N | 74LS189LSN | DIL16 | RAM:IC1, RAM:IC2 | 64-Bit Random Access Memory with 3-STATE Outputs
6 | 74LS245N | 74LS245N | DIL20 | ALU:IC5, IR:IC1, PC:IC2, RA:IC1, RAM:IC3, RB:IC1 | Octal BUS TRANSCEIVER, 3-state | 595-SN74LS245N
1 | 74LS273N | 74273N | DIL20 | OUT:IC3 | Octal D type FLIP FLOP, clear | 595-SN74LS273N
2 | 74LS283N | 74LS283N | DIL16 | ALU:IC1, ALU:IC2 | 4-bit binary FULL ADDER, fast carry | 595-SN74LS283N
1 | 74LS32N | 74LS32N | DIL14 | CLK:IC5 | Quad 2-input OR gate | 595-SN74LS32N
1 | 74LS76N | 7476N | DIL16 | OUT:IC5 | Dual J-K FLIP FLOP, preset and clear
2 | 74LS86N | 74LS86N | DIL14 | ALU:IC3, ALU:IC4 | Quad 2-input EXCLUSIV-OR (XOR) gate | 595-SN74LS86AN
14 | BLUE | LED3MM | LED3MM | IR:LED5, IR:LED6, IR:LED7, IR:LED8, MAR:LED1, MAR:LED2, MAR:LED3, MAR:LED4, PC:LED1, PC:LED2, PC:LED3, PC:LED4, SR:LED1, SR:LED2 | LED | 743-INL-3AB30
1 | DC-JACK | DC-JACK | POWER_JACK_PTH | U$1
6 | GREEN | LED3MM | LED3MM | ID:T0, ID:T1, ID:T2, ID:T3, ID:T4, MAR:RUN | LED | 859-LTL-4232N
4 | LM555 | LM555 | DIP8 | CLK:IC2, CLK:IC3, CLK:IC4, OUT:IC4 |  | 926-LM555CN/NOPB
4 | MOUNT-PAD-ROUND3.2 | MOUNT-PAD-ROUND3.2 | 3,2-PAD | H1, H2, H3, H4 | MOUNTING PAD, round
1 | Memory Address | DIP04YL | DIP04YL | MAR:S1 | DIL/CODE SWITCH | 611-BDB04
1 | Memory Data | DIP08YL | DIP08YL | RAM:S2 | DIL/CODE SWITCH | 611-BDB08
1 | Program / Write | SWITCH-SPDT-PTH-11.6X4.0MM-KIT | SWITCH_SPDT_PTH_11.6X4.0MM_KIT | MAR:S3 | Single Pole, Double Throw (SPDT) Switch | 474-COM-00102
4 | RED | 7SEG-CK | 7SEG-13 | OUT:D1, OUT:D2, OUT:D3, OUT:D4 | 7-segment DISPLAY | 859-LTS-5003AWC
62 | RED | LED3MM | LED3MM | ALU:LED1, ALU:LED2, ALU:LED3, ALU:LED4, ALU:LED5, ALU:LED6, ALU:LED7, ALU:LED8, CLK:LED1, ID:AI, ID:AO, ID:BI, ID:CE, ID:CO, ID:EO, ID:FI, ID:HLT, ID:II, ID:IO, ID:JP, ID:MI, ID:OI, ID:RI, ID:RO, ID:SU, IR:LED1, IR:LED2, IR:LED3, IR:LED4, LED1, LED2, LED3, LED4, LED5, LED6, LED7, LED8, MAR:PROG, RA:LED1, RA:LED2, RA:LED3, RA:LED4, RA:LED5, RA:LED6, RA:LED7, RA:LED8, RAM:LED1, RAM:LED2, RAM:LED3, RAM:LED4, RAM:LED5, RAM:LED6, RAM:LED7, RAM:LED8, RB:LED1, RB:LED2, RB:LED3, RB:LED4, RB:LED5, RB:LED6, RB:LED7, RB:LED8 | LED | 743-INL-3AR30
1 | Reset | MOMENTARY-SWITCH-SPST-PTH-12MM | TACTILE_SWITCH_PTH_12MM | ID:S1 | Momentary Switch (Pushbutton) - SPST | 474-COM-09190
1 | Single Step | MOMENTARY-SWITCH-SPST-PTH-12MM | TACTILE_SWITCH_PTH_12MM | CLK:S1 | Momentary Switch (Pushbutton) - SPST | 474-COM-09190
1 | Source Select | SWITCH-SPDT-PTH-11.6X4.0MM-KIT | SWITCH_SPDT_PTH_11.6X4.0MM_KIT | CLK:S2 | Single Pole, Double Throw (SPDT) Switch | 474-COM-00102
2 | TERMINAL-1BRIDGE | TERMINAL-1BRIDGE | VOGT-1098A.68 | J1, J2
60 | TPTP06R | TPTP06R | TP06R | CLK:TP1, CLK:TP2, CLK:TP3, CLK:TP4, ID:TP1, ID:TP2, ID:TP3, ID:TP4, ID:TP5, ID:TP6, ID:TP7, ID:TP8, ID:TP9, ID:TP10, ID:TP11, ID:TP12, ID:TP13, ID:TP14, ID:TP15, ID:TP16, ID:TP17, ID:TP18, ID:TP19, ID:TP20, ID:TP21, ID:TP22, ID:TP23, ID:TP24, ID:TP25, ID:TP26, ID:TP27, ID:TP28, ID:TP29, ID:TP30, ID:TP31, ID:TP32, ID:TP33, ID:TP34, ID:TP35, ID:TP36, SR:TP1, SR:TP2, SR:TP3, SR:TP4, TP1, TP2, TP3, TP4, TP5, TP6, TP7, TP8, TP9, TP10, TP11, TP12, TP13, TP14, TP15, TP16 | Test pad
1 | Write Byte | MOMENTARY-SWITCH-SPST-PTH-12MM | TACTILE_SWITCH_PTH_12MM | RAM:S1 | Momentary Switch (Pushbutton) - SPST | 474-COM-09190
14 |  | DIP14-SOCKET |  |  |  | 649-DILB14P-223TLF
21 |  | DIP16-SOCKET |  |  |  | 649-DILB16P-223TLF
7 |  | DIP20-SOCKET |  |  |  | 649-DILB20P-223TLF
4 |  | DIP08-SOCKET |  |  |  | 649-DILB8P223TLF
3 |  | DIP24W-SOCKET |  |  |  | 649-DILB24P-223TLF

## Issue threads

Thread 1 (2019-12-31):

Error on the inverter for the clock module ?

wawachief, 2019-12-31:
Hi,
first, I want to thank you for the great job you did on this project. I am a big fan of Ben Eater's videos on the 8 bit computer but not everyone is a breadboard master like he is ! Your project allows me to play with this computer... as soon as I get it toi work properly !

I have several issues I try to figure out. First one is with the inverter you use on the clock module : The 74ls06 needs puul-ups as its outputs are open collectors. Ben uses 74ls04. Is it a mistake in the silkscreen or do you really mean 74ls06 ?  I had  to add  pullups on the pins 2 - 4 - 6 to get a clock pulse.

dangrie158, 2020-01-14:
Ha! you are completely right. Problem was I only had an LS06 in my parts library and changed the value for all parts simply to 04 as the pinout and symbol is the same. Forgot this one, thanks for spotting!

I updated the silkscreen, schematic, BOM and gerbers

jpbiley, 2020-02-19:
I had made a board using the Gubers downloaded on Nov 2019.  Is this just a chip swap or do retrofit this version of the board?  the clock appears to be working I can add values to ram, read values in ram, run the clock, single step and even get numeric output on the 7 segment displays.  however every instruction seem to cause a halt condition my the third step in the microcode.

Any hints would be appreciated.  Thank you for making this system available.

softtribe, 2020-02-24:
Hi Daniel,
Thank you for sharing your design and for the awesome documentation.
Like @jpbiley I have manufactured 2 PCBs with the gerbers from August 2019.
The clock is working fine 74LS06 and 74LS04, but like @jpbiley I have the same issues on both boards : the halt flag appearing on the 3rd step of the microcode. I don't think the source cause is my EEPROMS because I have swapped them, verified their content, and recompiled the uCode using your Python library and tools.
Have you any suggestion for further debugging ?

dangrie158, 2020-02-24:
Hi,
Did you have a look at #2 ?
Make sure that i1-i4 are not connected via the buffer to the database but instead directly from the Flipflops to the micro code decoders.

Maybe check ne new Gerbers or if you have eagle installed the schematic. Sounds like you have the old version of the board

dangrie158, 2020-02-24:
Maybe check this picture : https://twitter.com/danielgriehaber/status/1160595950110461952?s=21

softtribe, 2020-02-24:
Thank you Daniel.
The issue was #2 (problem with the instruction register buffer connection to the bus). With the correction that you have already implemented the computer works fine now.
The only issue that remains for programs containing the OUT instruction : the output segments are displaying 0224 when OI is enabled (on the micro-step T2).
I'm so excited to play with the programming of the processor, thank you again !

jpbiley, 2020-04-01:
I installed the jumpers and updated to the Jan 14 LUT code as all works well.  Thank you for the updates.

jpbiley, 2020-04-01:
I added the suggested jumpers and reprogramed the LUT's with the Jan 14 code.  Now everything works correctly, thank you for these updates!

Closed 2020-01-14.

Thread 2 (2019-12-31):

Problem with the instruction register module

wawachief, 2019-12-31:
Hi. I have a problem with the instruction register tri-state buffer (74ls245): If I understand well, the I1-I4 signals which contains the instruction opcode should be connected to the instruction decoder even when the IO signal is HIGH. Therefore, the I1-i4 signals should be connected to the A side of the 74ls245 and not the B side.
To get it work I soldered some wired between theses two sides (9<->11, 8<->12, 7<->13 and 6<->14). Now I can execute a program without problems, but maybe I missed something ?

dangrie158, 2020-01-14:
Hi,

I noticed this error myself when assembling my board, however it seems like I forgot to update the gerbers although I changed the layout to fix this issue. I just regenerated the Gerber files in 1d605bafe7777c3e55336b4e8abfb66d250fa5d7

Closed 2020-01-14.

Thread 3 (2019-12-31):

Problem with the display OUTput

wawachief, 2019-12-31:
I have a last issue with the computer : the 7-segments display don't work properly. I don't understand how this is supposed to work with the resistors array.
To fix that, I desoldered the resistors and soldered the output decoder D0->D7 directly to the 7-segments display, assuming the IC would limit the current as ben suggested in his videos.

dangrie158, 2020-01-14:
Mhh, I had no issues. Do you use blue or white displays?
I just added a section in the docs explaining possible solutions (lowering the network values, jumping it out completely), although the "right" solution would be to add a drive transistor for each network, but even when using a IC (like a ULNXXX series) the rerouting of the board and additional space needed probably makes it not worth just for the "correct" solution instead of a fix.

Closed 2020-01-14.

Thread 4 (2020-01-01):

Problem with LDI instruction

wawachief, 2020-01-01:
when I execute LDI 0x1, the A register contains 0b11110001 instead of 0b00000001. The high nibble is put to 0xF instead of 0x0.

wawachief, 2020-01-02:
This is my fault : I had a bad solder on the bus pull-down resistor array. It is fixed now

wawachief, 2020-01-02:
This is my fault : I had a bad solder on the bus pull-down resistor array. It is fixed now

Closed 2020-01-02.

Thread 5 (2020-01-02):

Problem with JC instruction

wawachief, 2020-01-02:
JC instruction seems not to be working : I can see the Carry LED turn on but JC continues without jumping.
I believe I figured out the problem : the CF flag is connected to A8 on the EEPROM and ZF to A9, so in lut_microcode.py, there should be
FLAG_CF = 1 << 8
FLAG_ZF = 1 << 9
With theses changes, JC works fine.

dangrie158, 2020-01-14:
Thanks for reporting this, I just changed the flipped bit positions

Closed 2020-01-14.

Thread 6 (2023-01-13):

Emulator Question

William-Brumble, 2023-01-13:
Is the emulator in working order?
I'm playing around with it and can't get it to take the programs in the example program folder.

When trying to run them I get the error below:

```text
(venv) .\sap-1\SAP-1> python .\Emulator\main.py .\Example-Programs\Counter.s
Traceback (most recent call last):
  File "F:\coding\github\sap-1\SAP-1\Emulator\main.py", line 274, in <module>
    curses.wrapper(partial(main, args))
  File "C:\Users\William.B.Brumble\AppData\Local\Programs\Python\Python310\lib\curses\__init__.py", line 94, in wrapper
    return func(stdscr, *args, **kwds)
  File "F:\coding\github\sap-1\SAP-1\Emulator\main.py", line 21, in main
    processor.load_program(args.assembly)
  File "F:\coding\github\sap-1\SAP-1\Emulator\lib\sap1.py", line 82, in load_program
    self.program = Tools.asm.parseFile(program_file)
  File "F:\coding\github\sap-1\SAP-1\Emulator\lib\../..\Tools\asm.py", line 190, in parseFile
    raise SyntaxError(f"Unknown instruction: {mnemo}.", (file_path, cur_line, 0, line))
  File "F:\coding\github\sap-1\SAP-1\Example-Programs\Counter.s", line 1
    .data:
0xF: 0x1

LDA 0xF
loop:
OUT
SUB 0xF
JMP loop
SyntaxError: Unknown instruction: .data:
0xF:.
(venv) .\sap-1\SAP-1>
```

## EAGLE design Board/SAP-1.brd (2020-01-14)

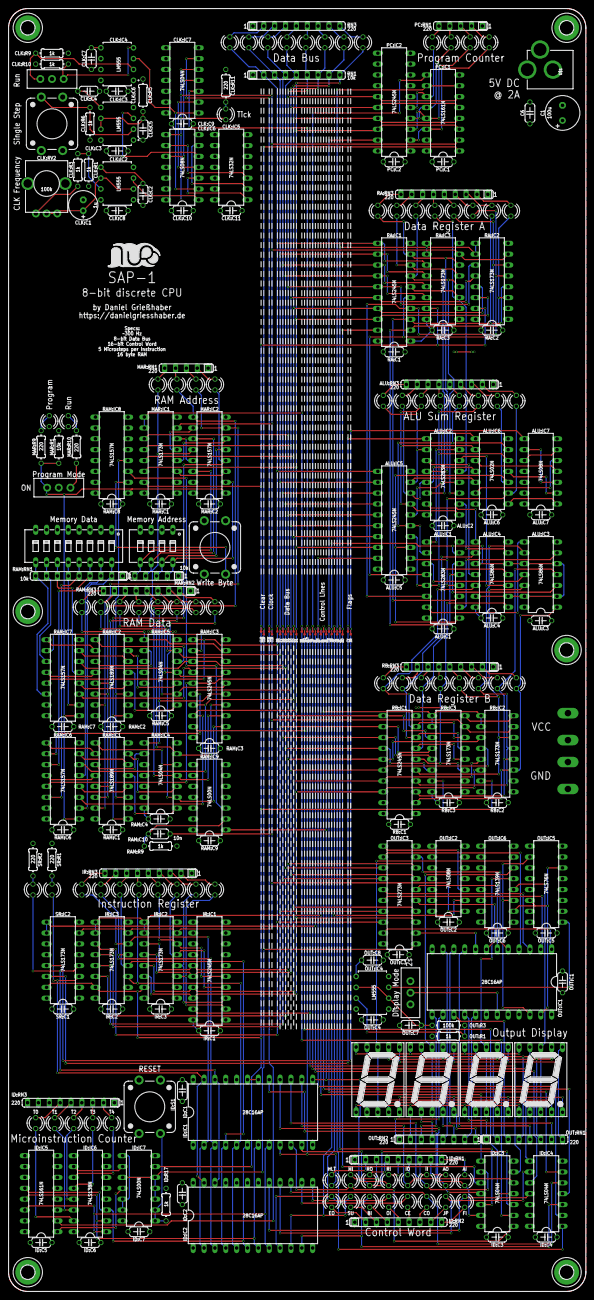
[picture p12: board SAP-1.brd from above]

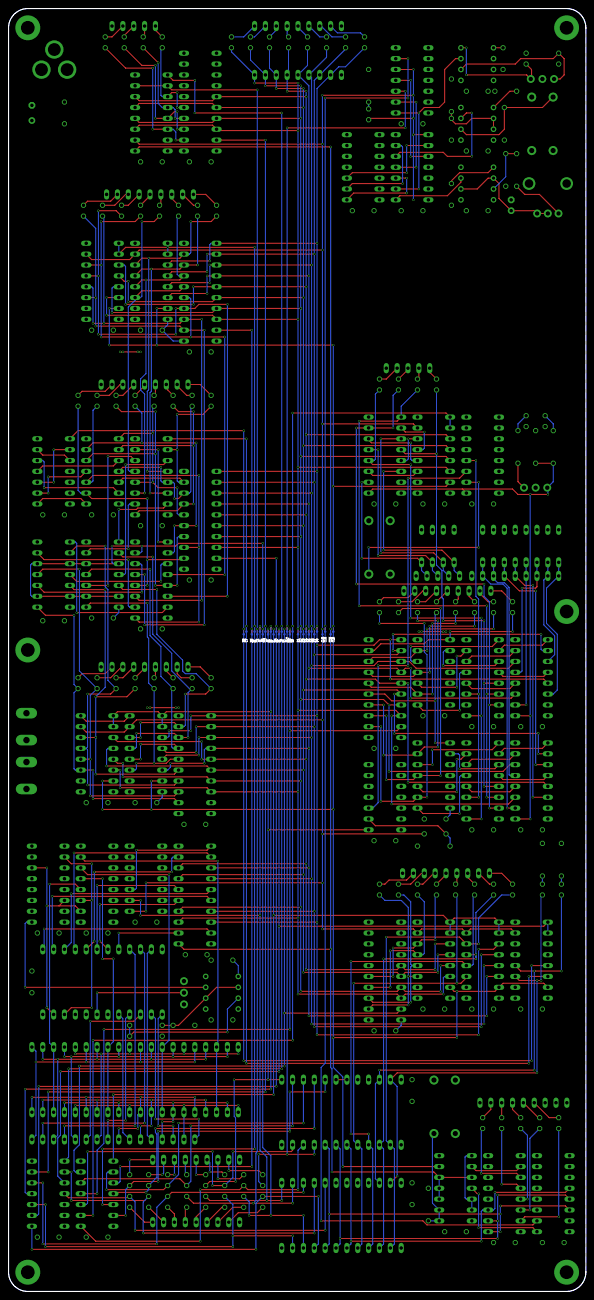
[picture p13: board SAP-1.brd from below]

Board: 2 copper layers, 135.0 x 300.0 mm, 305 parts (30 on the bottom side), 294 nets.

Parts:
ALU:C1, ALU:C2, ALU:C3, ALU:C4, ALU:C5, ALU:C6, ALU:C7: 100n; C050-024X044
ALU:IC1, ALU:IC2: 74LS283N; DIL16
ALU:IC3, ALU:IC4: 74LS86N; DIL14
ALU:IC5: 74LS245N; DIL20
ALU:IC6: 74LS02N; DIL14
ALU:IC7: 74LS08N; DIL14
ALU:LED1, ALU:LED2, ALU:LED3, ALU:LED4, ALU:LED5, ALU:LED6, ALU:LED7, ALU:LED8: RED; LED3MM
ALU:RN3: 220; SIL9
C1: 100u; E3,5-8
C6: 100n; C050-024X044
CLK:C1: 1u; E2,5-7
CLK:C2, CLK:C3, CLK:C4, CLK:C5, CLK:C6, CLK:C7, CLK:C8, CLK:C9, CLK:C10, CLK:C11: 100n; C050-024X044
CLK:IC2, CLK:IC3, CLK:IC4: LM555; DIP8
CLK:IC5: 74LS32N; DIL14
CLK:IC6: 74LS08N; DIL14
CLK:IC7: 74LS04N; DIL14
CLK:LED1: RED; LED3MM
CLK:R1, CLK:R3, CLK:R6, CLK:R9, CLK:R10: 1k; 0204/7
CLK:R5: 1M; 0204/7
CLK:R11: 220; 0204/7
CLK:RV2: 100k; ALPS_POT_KIT
CLK:S1: Single Step; TACTILE_SWITCH_PTH_12MM
CLK:S2: Source Select; SWITCH_SPDT_PTH_11.6X4.0MM_KIT
CLK:TP1, CLK:TP2, CLK:TP3, CLK:TP4: TPTP06R; TP06R
H1, H2, H3, H4: MOUNT-PAD-ROUND3.2; 3,2-PAD
H5, H6: 3.2; 3,2-PAD
ID:AI: RED; LED3MM
ID:AO: RED; LED3MM
ID:BI: RED; LED3MM
ID:C1, ID:C2, ID:C3, ID:C4, ID:C5, ID:C6, ID:C7: 100n; C050-024X044
ID:CE: RED; LED3MM
ID:CO: RED; LED3MM
ID:EO: RED; LED3MM
ID:FI: RED; LED3MM
ID:HLT: RED; LED3MM
ID:IC1, ID:IC2: 28C16AP; DIL24-6
ID:IC3, ID:IC4: 74LS04N; DIL14
ID:IC5: 74LS161N; DIL16
ID:IC6: 74LS138N; DIL16
ID:IC7: 74LS00N; DIL14
ID:II: RED; LED3MM
ID:IO: RED; LED3MM
ID:JP: RED; LED3MM
ID:MI: RED; LED3MM
ID:OI: RED; LED3MM
ID:R17: 1k; 0204/7
ID:RI: RED; LED3MM
ID:RN1, ID:RN2, ID:RN3: 220; SIL9
ID:RO: RED; LED3MM
ID:S1: Reset; TACTILE_SWITCH_PTH_12MM
ID:SU: RED; LED3MM
ID:T0, ID:T1, ID:T2, ID:T3, ID:T4: GREEN; LED3MM
ID:TP1, ID:TP2, ID:TP3, ID:TP4, ID:TP5, ID:TP6, ID:TP7, ID:TP8, ID:TP9, ID:TP10, ID:TP11, ID:TP12, ID:TP13, ID:TP14, ID:TP15, ID:TP16, ID:TP17, ID:TP18, ID:TP19, ID:TP20, ID:TP21, ID:TP22, ID:TP23, ID:TP24, ID:TP25, ID:TP26, ID:TP27, ID:TP28, ID:TP29, ID:TP30, ID:TP31, ID:TP32, ID:TP33, ID:TP34, ID:TP35, ID:TP36: TPTP06R; TP06R
IR:C1, IR:C2, IR:C3: 100n; C050-024X044
IR:IC1: 74LS245N; DIL20
IR:IC2, IR:IC3: 74LS173N; DIL16
IR:LED1, IR:LED2, IR:LED3, IR:LED4: RED; LED3MM
IR:LED5, IR:LED6, IR:LED7, IR:LED8: BLUE; LED3MM
IR:RN3: 220; SIL9
J1, J2: TERMINAL-1BRIDGE; VOGT-1098A.68
LED1, LED2, LED3, LED4, LED5, LED6, LED7, LED8: RED; LED3MM
MAR:C1, MAR:C2: 100n; C050-024X044
MAR:IC1: 74LS173N; DIL16
MAR:IC2: 74LS157N; DIL16
MAR:LED1, MAR:LED2, MAR:LED3, MAR:LED4: BLUE; LED3MM
MAR:PROG: RED; LED3MM
MAR:R1: 10k; 0204/7
MAR:R9, MAR:R10: 220; 0204/7
MAR:RN1: 220; SIL5
MAR:RN2: 10k; SIL5
MAR:RUN: GREEN; LED3MM
MAR:S1: Memory Address; DIP04YL
MAR:S3: Program / Write; SWITCH_SPDT_PTH_11.6X4.0MM_KIT
OUT:C1, OUT:C2, OUT:C3, OUT:C4, OUT:C5, OUT:C6, OUT:C8: 100n; C050-024X044
OUT:C7: 10n; C050-024X044
OUT:D1, OUT:D2, OUT:D3, OUT:D4: RED; 7SEG-13
OUT:IC1: 28C16AP; DIL24-6
OUT:IC2: 74LS08N; DIL14
OUT:IC3: 74LS273N; DIL20
OUT:IC4: LM555; DIP8
OUT:IC5: 74LS76N; DIL16
OUT:IC6: 74LS139N; DIL16
OUT:R1: 1k; 0204/7
OUT:R3: 100k; 0204/7
OUT:RN1, OUT:RN2: 220; SIL8
OUT:S3: 2's Complement; SWITCH_SPDT_PTH_11.6X4.0MM_KIT
PC:C1, PC:C2: 100n; C050-024X044
PC:IC1: 74LS161N; DIL16
PC:IC2: 74LS245N; DIL20
PC:LED1, PC:LED2, PC:LED3, PC:LED4: BLUE; LED3MM
PC:RN1: 220; SIL5
RA:C1, RA:C2, RA:C3: 100n; C050-024X044
RA:IC1: 74LS245N; DIL20
RA:IC2, RA:IC3: 74LS173N; DIL16
RA:LED1, RA:LED2, RA:LED3, RA:LED4, RA:LED5, RA:LED6, RA:LED7, RA:LED8: RED; LED3MM
RA:RN3: 220; SIL9
RAM:C1, RAM:C2, RAM:C3, RAM:C4, RAM:C5, RAM:C6, RAM:C7, RAM:C8, RAM:C9: 100n; C050-024X044
RAM:C10: 10n; C050-024X044
RAM:IC1, RAM:IC2: 74LS189N; DIL16
RAM:IC3: 74LS245N; DIL20
RAM:IC4, RAM:IC5: 74LS04N; DIL14
RAM:IC6, RAM:IC7, RAM:IC8: 74LS157N; DIL16
RAM:IC9: 74LS00N; DIL14
RAM:LED1, RAM:LED2, RAM:LED3, RAM:LED4, RAM:LED5, RAM:LED6, RAM:LED7, RAM:LED8: RED; LED3MM
RAM:R9: 1k; 0204/7
RAM:RN1: 10k; SIL9
RAM:RN3: 220; SIL9
RAM:S1: Write Byte; TACTILE_SWITCH_PTH_12MM
RAM:S2: Memory Data; DIP08YL
RB:C1, RB:C2, RB:C3: 100n; C050-024X044
RB:IC1: 74LS245N; DIL20
RB:IC2, RB:IC3: 74LS173N; DIL16
RB:LED1, RB:LED2, RB:LED3, RB:LED4, RB:LED5, RB:LED6, RB:LED7, RB:LED8: RED; LED3MM
RB:RN3: 220; SIL9
RN1: 10k; SIL9
RN3: 220; SIL9
SR:C1: 100n; C050-024X044
SR:IC2: 74LS173N; DIL16
SR:LED1, SR:LED2: BLUE; LED3MM
SR:R1, SR:R2: 220; 0204/7
SR:TP1, SR:TP2, SR:TP3, SR:TP4: TPTP06R; TP06R
TP1, TP2, TP3, TP4, TP5, TP6, TP7, TP8, TP9, TP10, TP11, TP12, TP13, TP14, TP15, TP16: TPTP06R; TP06R
U$1: DC-JACK; POWER_JACK_PTH
U$2: LOGO-SILKSCREEN

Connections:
!AI: ID:IC3.12, ID:TP8.TP, ID:TP26.TP, RA:IC2.9, RA:IC2.10, RA:IC3.9, RA:IC3.10
!AO: ID:IC3.10, ID:TP7.TP, ID:TP25.TP, RA:IC1.19
!BI: ID:IC4.4, ID:TP11.TP, ID:TP29.TP, RB:IC2.9, RB:IC2.10, RB:IC3.9, RB:IC3.10
!CLK: CLK:IC7.6, CLK:TP1.TP, CLK:TP4.TP, ID:IC5.2
!CLR: ID:IC7.3, ID:IC7.4, ID:IC7.5, ID:IC7.10, ID:TP18.TP, ID:TP35.TP, OUT:IC3.1, PC:IC1.1
!CO: ID:IC4.6, ID:TP14.TP, ID:TP32.TP, PC:IC2.19
!EO: ALU:IC5.19, ID:IC4.2, ID:TP9.TP, ID:TP27.TP
!FI: ID:IC4.10, ID:TP16.TP, ID:TP34.TP, SR:IC2.9, SR:IC2.10
!II: ID:IC3.8, ID:TP6.TP, ID:TP24.TP, IR:IC2.9, IR:IC2.10, IR:IC3.9, IR:IC3.10
!IO: ID:IC3.6, ID:TP5.TP, ID:TP23.TP, IR:IC1.19
!JP: ID:IC4.8, ID:TP15.TP, ID:TP33.TP, PC:IC1.9
!MI: ID:IC3.2, ID:TP2.TP, ID:TP20.TP, MAR:IC1.9, MAR:IC1.10
!RO: ID:IC3.4, ID:TP3.TP, ID:TP21.TP, RAM:IC3.19
ALU:N$1: ALU:IC1.9, ALU:IC2.7
ALU:N$2: ALU:IC6.1, ALU:IC7.1
ALU:N$3: ALU:IC6.4, ALU:IC7.2
ALU:N$4: ALU:IC6.10, ALU:IC7.4
ALU:N$5: ALU:IC6.13, ALU:IC7.5
ALU:N$6: ALU:IC7.3, ALU:IC7.9
ALU:N$7: ALU:IC7.6, ALU:IC7.10
ALU:N$8: ALU:LED8.K, ALU:RN3.9
ALU:N$9: ALU:LED7.K, ALU:RN3.8
ALU:N$10: ALU:LED6.K, ALU:RN3.7
ALU:N$11: ALU:LED5.K, ALU:RN3.6
ALU:N$12: ALU:LED4.K, ALU:RN3.5
ALU:N$13: ALU:LED3.K, ALU:RN3.4
ALU:N$14: ALU:LED2.K, ALU:RN3.3
ALU:N$15: ALU:LED1.K, ALU:RN3.2
ALU:N$18: ALU:IC1.6, ALU:IC3.3
ALU:N$19: ALU:IC1.2, ALU:IC3.6
ALU:N$20: ALU:IC1.15, ALU:IC3.8
ALU:N$21: ALU:IC1.11, ALU:IC3.11
ALU:N$22: ALU:IC2.6, ALU:IC4.3
ALU:N$23: ALU:IC2.2, ALU:IC4.6
ALU:N$24: ALU:IC2.15, ALU:IC4.8
ALU:N$25: ALU:IC2.11, ALU:IC4.11
ALU:S1: ALU:IC1.4, ALU:IC5.2, ALU:IC6.2, ALU:LED1.A
ALU:S2: ALU:IC1.1, ALU:IC5.3, ALU:IC6.3, ALU:LED2.A
ALU:S3: ALU:IC1.13, ALU:IC5.4, ALU:IC6.5, ALU:LED3.A
ALU:S4: ALU:IC1.10, ALU:IC5.5, ALU:IC6.6, ALU:LED4.A
ALU:S5: ALU:IC2.4, ALU:IC5.6, ALU:IC6.8, ALU:LED5.A
ALU:S6: ALU:IC2.1, ALU:IC5.7, ALU:IC6.9, ALU:LED6.A
ALU:S7: ALU:IC2.13, ALU:IC5.8, ALU:IC6.11, ALU:LED7.A
ALU:S8: ALU:IC2.10, ALU:IC5.9, ALU:IC6.12, ALU:LED8.A
CE: ID:CE.A, ID:IC2.14, ID:TP13.TP, ID:TP31.TP, PC:IC1.7, PC:IC1.10
CF: ID:IC1.23, ID:IC2.23, SR:IC2.3, SR:LED2.A
CLK: CLK:IC6.8, CLK:IC7.5, CLK:LED1.A, CLK:TP2.TP, CLK:TP3.TP, IR:IC2.7, IR:IC3.7, MAR:IC1.7, OUT:IC2.1, PC:IC1.2, RA:IC2.7, RA:IC3.7, RAM:C10.1, RB:IC2.7, RB:IC3.7, SR:IC2.7
CLK:CLK_SEL: CLK:IC4.3, CLK:IC6.2, CLK:IC7.1
CLK:CLK_STEP: CLK:IC3.3, CLK:IC6.5
CLK:CLK_TICK: CLK:IC2.3, CLK:IC6.1
CLK:N$1: CLK:C1.+, CLK:IC2.2, CLK:IC2.6, CLK:RV2.P$2, CLK:RV2.P$3
CLK:N$2: CLK:IC2.7, CLK:R1.1, CLK:R3.2
CLK:N$3: CLK:R3.1, CLK:RV2.P$1
CLK:N$4: CLK:LED1.K, CLK:R11.2
CLK:N$6: CLK:C2.1, CLK:IC2.5
CLK:N$7: CLK:IC3.2, CLK:R6.1, CLK:S1.3
CLK:N$8: CLK:C4.1, CLK:IC3.5
CLK:N$11: CLK:C5.1, CLK:IC3.6, CLK:IC3.7, CLK:R5.1
CLK:N$12: CLK:C7.1, CLK:IC4.5
CLK:N$13: CLK:IC6.4, CLK:IC7.2
CLK:N$14: CLK:IC5.1, CLK:IC6.3
CLK:N$15: CLK:IC4.2, CLK:R9.1, CLK:S2.1
CLK:N$16: CLK:IC4.4, CLK:R10.1, CLK:S2.3
CLK:N$17: CLK:IC5.2, CLK:IC6.6
CLK:N$18: CLK:IC5.3, CLK:IC6.9
CLK:N$19: CLK:IC6.10, CLK:IC7.4
CLR: ID:IC7.6, ID:TP17.TP, ID:TP36.TP, IR:IC2.15, IR:IC3.15, MAR:IC1.15, RA:IC2.15, RA:IC3.15, RB:IC2.15, RB:IC3.15, SR:IC2.15
CY: ALU:IC2.9, SR:IC2.14, SR:TP1.TP, SR:TP4.TP
D1: ALU:IC5.18, IR:IC1.18, IR:IC2.14, LED1.A, MAR:IC1.14, OUT:IC3.3, PC:IC1.3, PC:IC2.18, RA:IC1.18, RA:IC2.14, RAM:IC3.18, RAM:IC6.3, RB:IC1.18, RB:IC2.14, RN1.9, TP8.TP, TP16.TP
D2: ALU:IC5.17, IR:IC1.17, IR:IC2.13, LED2.A, MAR:IC1.13, OUT:IC3.4, PC:IC1.4, PC:IC2.17, RA:IC1.17, RA:IC2.13, RAM:IC3.17, RAM:IC6.6, RB:IC1.17, RB:IC2.13, RN1.8, TP7.TP, TP15.TP
D3: ALU:IC5.16, IR:IC1.16, IR:IC2.12, LED3.A, MAR:IC1.12, OUT:IC3.7, PC:IC1.5, PC:IC2.16, RA:IC1.16, RA:IC2.12, RAM:IC3.16, RAM:IC6.10, RB:IC1.16, RB:IC2.12, RN1.7, TP6.TP, TP14.TP
D4: ALU:IC5.15, IR:IC1.15, IR:IC2.11, LED4.A, MAR:IC1.11, OUT:IC3.8, PC:IC1.6, PC:IC2.15, RA:IC1.15, RA:IC2.11, RAM:IC3.15, RAM:IC6.13, RB:IC1.15, RB:IC2.11, RN1.6, TP5.TP, TP13.TP
D5: ALU:IC5.14, IR:IC3.14, LED5.A, OUT:IC3.13, RA:IC1.14, RA:IC3.14, RAM:IC3.14, RAM:IC7.3, RB:IC1.14, RB:IC3.14, RN1.5, TP4.TP, TP12.TP
D6: ALU:IC5.13, IR:IC3.13, LED6.A, OUT:IC3.14, RA:IC1.13, RA:IC3.13, RAM:IC3.13, RAM:IC7.6, RB:IC1.13, RB:IC3.13, RN1.4, TP3.TP, TP11.TP
D7: ALU:IC5.12, IR:IC3.12, LED7.A, OUT:IC3.17, RA:IC1.12, RA:IC3.12, RAM:IC3.12, RAM:IC7.10, RB:IC1.12, RB:IC3.12, RN1.3, TP2.TP, TP10.TP
D8: ALU:IC5.11, IR:IC3.11, LED8.A, OUT:IC3.18, RA:IC1.11, RA:IC3.11, RAM:IC3.11, RAM:IC7.13, RB:IC1.11, RB:IC3.11, RN1.2, TP1.TP, TP9.TP
GND: ALU:C1.2, ALU:C2.2, ALU:C3.2, ALU:C4.2, ALU:C5.2, ALU:C6.2, ALU:C7.2, ALU:IC1.8, ALU:IC2.8, ALU:IC3.7, ALU:IC4.7, ALU:IC5.10, ALU:IC6.7, ALU:IC7.7, ALU:IC7.12, ALU:IC7.13, ALU:RN3.1, C1.-, C6.2, CLK:C1.-, CLK:C2.2, CLK:C3.2, CLK:C4.2, CLK:C5.2, CLK:C6.2, CLK:C7.2, CLK:C8.2, CLK:C9.2, CLK:C10.2, CLK:C11.2, CLK:IC2.1, CLK:IC3.1, CLK:IC4.1, CLK:IC4.6, CLK:IC4.7, CLK:IC5.4, CLK:IC5.5, CLK:IC5.7, CLK:IC5.9, CLK:IC5.10, CLK:IC5.12, CLK:IC5.13, CLK:IC6.7, CLK:IC6.12, CLK:IC6.13, CLK:IC7.7, CLK:IC7.9, CLK:IC7.11, CLK:IC7.13, CLK:R11.1, CLK:S1.1, CLK:S2.2, H1.B3,2, H2.B3,2, H3.B3,2, H4.B3,2, H5.B3,2, H6.B3,2, ID:C1.2, ID:C2.2, ID:C3.2, ID:C4.2, ID:C5.2, ID:C6.2, ID:C7.2, ID:IC1.1, ID:IC1.12, ID:IC1.18, ID:IC1.19, ID:IC1.20, ID:IC2.12, ID:IC2.18, ID:IC2.19, ID:IC2.20, ID:IC3.7, ID:IC4.7, ID:IC4.13, ID:IC5.3, ID:IC5.4, ID:IC5.5, ID:IC5.6, ID:IC5.8, ID:IC6.4, ID:IC6.5, ID:IC6.8, ID:IC7.7, ID:R17.1, ID:RN1.1, ID:RN2.1, ID:RN3.1, IR:C1.2, IR:C2.2, IR:C3.2, IR:IC1.6, IR:IC1.7, IR:IC1.8, IR:IC1.9, IR:IC1.10, IR:IC2.1, IR:IC2.2, IR:IC2.8, IR:IC3.1, IR:IC3.2, IR:IC3.8, IR:RN3.1, J2.P$1, J2.P$2, MAR:C1.2, MAR:C2.2, MAR:IC1.1, MAR:IC1.2, MAR:IC1.8, MAR:IC2.8, MAR:IC2.15, MAR:RN1.1, MAR:S1.1, MAR:S1.2, MAR:S1.3, MAR:S1.4, MAR:S3.2, OUT:C1.2, OUT:C2.2, OUT:C3.2, OUT:C4.2, OUT:C5.2, OUT:C6.2, OUT:C7.2, OUT:C8.2, OUT:IC1.12, OUT:IC1.18, OUT:IC1.20, OUT:IC2.4, OUT:IC2.5, OUT:IC2.7, OUT:IC2.9, OUT:IC2.10, OUT:IC2.12, OUT:IC2.13, OUT:IC3.10, OUT:IC4.1, OUT:IC5.13, OUT:IC6.1, OUT:IC6.8, OUT:IC6.13, OUT:IC6.14, OUT:S3.1, PC:C1.2, PC:C2.2, PC:IC1.8, PC:IC2.6, PC:IC2.7, PC:IC2.8, PC:IC2.9, PC:IC2.10, PC:RN1.1, RA:C1.2, RA:C2.2, RA:C3.2, RA:IC1.10, RA:IC2.1, RA:IC2.2, RA:IC2.8, RA:IC3.1, RA:IC3.2, RA:IC3.8, RA:RN3.1, RAM:C1.2, RAM:C2.2, RAM:C3.2, RAM:C4.2, RAM:C5.2, RAM:C6.2, RAM:C7.2, RAM:C8.2, RAM:C9.2, RAM:IC1.2, RAM:IC1.8, RAM:IC2.2, RAM:IC2.8, RAM:IC3.10, RAM:IC4.7, RAM:IC4.11, RAM:IC4.13, RAM:IC5.7, RAM:IC5.11, RAM:IC5.13, RAM:IC6.8, RAM:IC6.15, RAM:IC7.8, RAM:IC7.15, RAM:IC8.5, RAM:IC8.6, RAM:IC8.8, RAM:IC8.10, RAM:IC8.11, RAM:IC8.13, RAM:IC8.14, RAM:IC8.15, RAM:IC9.4, RAM:IC9.5, RAM:IC9.7, RAM:IC9.9, RAM:IC9.10, RAM:IC9.12, RAM:IC9.13, RAM:R9.1, RAM:RN3.1, RAM:S1.1, RAM:S2.1, RAM:S2.2, RAM:S2.3, RAM:S2.4, RAM:S2.5, RAM:S2.6, RAM:S2.7, RAM:S2.8, RB:C1.2, RB:C2.2, RB:C3.2, RB:IC1.10, RB:IC2.1, RB:IC2.2, RB:IC2.8, RB:IC3.1, RB:IC3.2, RB:IC3.8, RB:RN3.1, RN1.1, RN3.1, SR:C1.2, SR:IC2.1, SR:IC2.2, SR:IC2.8, SR:IC2.11, SR:IC2.12, SR:R1.1, SR:R2.1, U$1.GND, U$1.GNDBREAK
HLT: CLK:IC7.3, ID:HLT.A, ID:IC1.9, ID:TP1.TP, ID:TP19.TP
ID:!T0: ID:IC6.15, ID:T0.A
ID:!T1: ID:IC6.14, ID:T1.A
ID:!T2: ID:IC6.13, ID:T2.A
ID:!T3: ID:IC6.12, ID:T3.A
ID:!T4: ID:IC6.11, ID:T4.A
ID:AI: ID:AI.A, ID:IC1.17, ID:IC3.13
ID:AO: ID:AO.A, ID:IC1.16, ID:IC3.11
ID:BI: ID:BI.A, ID:IC2.11, ID:IC4.3
ID:CO: ID:CO.A, ID:IC2.15, ID:IC4.5
ID:EO: ID:EO.A, ID:IC2.9, ID:IC4.1
ID:FI: ID:FI.A, ID:IC2.17, ID:IC4.11
ID:II: ID:IC1.15, ID:IC3.9, ID:II.A
ID:IO: ID:IC1.14, ID:IC3.5, ID:IO.A
ID:JP: ID:IC2.16, ID:IC4.9, ID:JP.A
ID:MI: ID:IC1.10, ID:IC3.1, ID:MI.A
ID:MI1: ID:IC1.8, ID:IC2.8, ID:IC5.14, ID:IC6.1
ID:MI2: ID:IC1.7, ID:IC2.7, ID:IC5.13, ID:IC6.2
ID:MI3: ID:IC1.6, ID:IC2.6, ID:IC5.12, ID:IC6.3
ID:N$1: ID:HLT.K, ID:RN1.2
ID:N$2: ID:MI.K, ID:RN1.3
ID:N$3: ID:RN1.4, ID:RO.K
ID:N$4: ID:RI.K, ID:RN1.5
ID:N$5: ID:IO.K, ID:RN1.6
ID:N$6: ID:II.K, ID:RN1.7
ID:N$7: ID:AO.K, ID:RN1.8
ID:N$8: ID:AI.K, ID:RN1.9
ID:N$9: ID:EO.K, ID:RN2.2
ID:N$10: ID:RN2.3, ID:SU.K
ID:N$11: ID:BI.K, ID:RN2.4
ID:N$12: ID:OI.K, ID:RN2.5
ID:N$13: ID:CE.K, ID:RN2.6
ID:N$14: ID:CO.K, ID:RN2.7
ID:N$15: ID:JP.K, ID:RN2.8
ID:N$16: ID:IC7.1, ID:IC7.2, ID:R17.2, ID:S1.3
ID:N$17: ID:IC5.1, ID:IC7.11
ID:N$18: ID:IC7.8, ID:IC7.12, ID:IC7.13
ID:N$19: ID:IC6.10, ID:IC7.9
ID:N$31: ID:FI.K, ID:RN2.9
ID:N$33: ID:RN3.4, ID:T2.K
ID:N$34: ID:RN3.2, ID:T4.K
ID:N$35: ID:RN3.3, ID:T3.K
ID:N$36: ID:RN3.5, ID:T1.K
ID:N$37: ID:RN3.6, ID:T0.K
ID:RO: ID:IC1.11, ID:IC3.3, ID:RO.A
IR:B1: IR:IC1.2, IR:IC2.3, IR:LED1.A
IR:B2: IR:IC1.3, IR:IC2.4, IR:LED2.A
IR:B3: IR:IC1.4, IR:IC2.5, IR:LED3.A
IR:B4: IR:IC1.5, IR:IC2.6, IR:LED4.A
IR:N$1: IR:LED8.K, IR:RN3.9
IR:N$2: IR:LED7.K, IR:RN3.8
IR:N$3: IR:LED6.K, IR:RN3.7
IR:N$5: IR:LED5.K, IR:RN3.6
IR:N$6: IR:LED4.K, IR:RN3.5
IR:N$7: IR:LED3.K, IR:RN3.4
IR:N$8: IR:LED2.K, IR:RN3.3
IR:N$9: IR:LED1.K, IR:RN3.2
MAR:I5: MAR:IC1.3, MAR:IC2.3
MAR:I6: MAR:IC1.4, MAR:IC2.6
MAR:I7: MAR:IC1.5, MAR:IC2.10
MAR:I8: MAR:IC1.6, MAR:IC2.13
MAR:N$1: MAR:IC2.2, MAR:RN2.2, MAR:S1.8
MAR:N$2: MAR:LED4.K, MAR:RN1.5
MAR:N$3: MAR:IC2.5, MAR:RN2.3, MAR:S1.7
MAR:N$4: MAR:LED3.K, MAR:RN1.4
MAR:N$5: MAR:IC2.11, MAR:RN2.4, MAR:S1.6
MAR:N$7: MAR:R10.2, MAR:S3.3
MAR:N$8: MAR:LED2.K, MAR:RN1.3
MAR:N$9: MAR:PROG.K, MAR:R9.1
MAR:N$10: MAR:LED1.K, MAR:RN1.2
MAR:N$11: MAR:IC2.14, MAR:RN2.5, MAR:S1.5
MAR:N$13: MAR:R10.1, MAR:RUN.K
unnamed: ALU:IC2.12, RA:IC1.9, RA:IC3.6, RA:LED8.A
unnamed: ALU:IC2.14, RA:IC1.8, RA:IC3.5, RA:LED7.A
unnamed: ALU:IC2.3, RA:IC1.7, RA:IC3.4, RA:LED6.A
unnamed: ALU:IC2.5, RA:IC1.6, RA:IC3.3, RA:LED5.A
unnamed: ALU:IC1.12, RA:IC1.5, RA:IC2.6, RA:LED4.A
unnamed: ALU:IC1.14, RA:IC1.4, RA:IC2.5, RA:LED3.A
unnamed: ALU:IC1.3, RA:IC1.3, RA:IC2.4, RA:LED2.A
unnamed: ALU:IC1.5, RA:IC1.2, RA:IC2.3, RA:LED1.A
unnamed: ALU:IC3.1, RB:IC1.2, RB:IC2.3, RB:LED1.A
unnamed: ALU:IC3.4, RB:IC1.3, RB:IC2.4, RB:LED2.A
unnamed: ALU:IC3.9, RB:IC1.4, RB:IC2.5, RB:LED3.A
unnamed: ALU:IC3.12, RB:IC1.5, RB:IC2.6, RB:LED4.A
unnamed: ALU:IC4.1, RB:IC1.6, RB:IC3.3, RB:LED5.A
unnamed: ALU:IC4.4, RB:IC1.7, RB:IC3.4, RB:LED6.A
unnamed: ALU:IC4.9, RB:IC1.8, RB:IC3.5, RB:LED7.A
unnamed: ALU:IC4.12, RB:IC1.9, RB:IC3.6, RB:LED8.A
unnamed: MAR:IC2.4, MAR:LED1.A, RAM:IC1.1, RAM:IC2.1
unnamed: MAR:IC2.7, MAR:LED2.A, RAM:IC1.15, RAM:IC2.15
unnamed: MAR:IC2.9, MAR:LED3.A, RAM:IC1.14, RAM:IC2.14
unnamed: MAR:IC2.12, MAR:LED4.A, RAM:IC1.13, RAM:IC2.13
unnamed: MAR:IC2.1, MAR:R1.2, MAR:R9.2, MAR:S3.1, RAM:IC6.1, RAM:IC7.1, RAM:IC8.1
unnamed: LED8.K, RN3.2
unnamed: LED7.K, RN3.3
unnamed: LED6.K, RN3.4
unnamed: LED5.K, RN3.5
unnamed: LED4.K, RN3.6
unnamed: LED3.K, RN3.7
unnamed: LED2.K, RN3.8
unnamed: LED1.K, RN3.9
unnamed: ID:IC1.5, ID:IC2.5, IR:IC3.3, IR:LED5.A
unnamed: ID:IC1.4, ID:IC2.4, IR:IC3.4, IR:LED6.A
unnamed: ID:IC1.3, ID:IC2.3, IR:IC3.5, IR:LED7.A
unnamed: ID:IC1.2, ID:IC2.2, IR:IC3.6, IR:LED8.A
OI: ID:IC2.13, ID:OI.A, ID:TP12.TP, ID:TP30.TP, OUT:IC2.2
OUT:2SC: OUT:IC1.19, OUT:S3.2
OUT:DIG1: OUT:D1.3, OUT:D1.8, OUT:IC6.4
OUT:DIG2: OUT:D2.3, OUT:D2.8, OUT:IC6.5
OUT:DIG3: OUT:D3.3, OUT:D3.8, OUT:IC6.6
OUT:DIG4: OUT:D4.3, OUT:D4.8, OUT:IC6.7
OUT:DISP_CLK: OUT:IC4.3, OUT:IC5.1
OUT:DS1: OUT:IC1.23, OUT:IC5.6, OUT:IC5.14, OUT:IC6.2
OUT:DS2: OUT:IC1.22, OUT:IC5.10, OUT:IC6.3
OUT:N$1: OUT:IC1.8, OUT:IC3.2
OUT:N$2: OUT:IC1.7, OUT:IC3.5
OUT:N$3: OUT:IC1.6, OUT:IC3.6
OUT:N$4: OUT:IC1.5, OUT:IC3.9
OUT:N$5: OUT:IC1.4, OUT:IC3.12
OUT:N$6: OUT:IC1.3, OUT:IC3.15
OUT:N$7: OUT:IC1.2, OUT:IC3.16
OUT:N$8: OUT:IC1.1, OUT:IC3.19
OUT:N$9: OUT:IC2.3, OUT:IC3.11
OUT:N$10: OUT:C7.1, OUT:IC4.2, OUT:IC4.6, OUT:R3.1
OUT:N$13: OUT:IC4.7, OUT:R1.1, OUT:R3.2
OUT:N$15: OUT:C8.1, OUT:IC4.5
OUT:N$17: OUT:IC1.14, OUT:RN2.1
OUT:SEG_A: OUT:D1.7, OUT:D2.7, OUT:D3.7, OUT:D4.7, OUT:RN1.6
OUT:SEG_AO: OUT:IC1.9, OUT:RN1.5
OUT:SEG_B: OUT:D1.6, OUT:D2.6, OUT:D3.6, OUT:D4.6, OUT:RN1.8
OUT:SEG_BO: OUT:IC1.10, OUT:RN1.7
OUT:SEG_C: OUT:D1.4, OUT:D2.4, OUT:D3.4, OUT:D4.4, OUT:RN2.6
OUT:SEG_CO: OUT:IC1.11, OUT:RN2.5
OUT:SEG_D: OUT:D1.2, OUT:D2.2, OUT:D3.2, OUT:D4.2, OUT:RN2.4
OUT:SEG_DO: OUT:IC1.13, OUT:RN2.3
OUT:SEG_DP: OUT:D1.5, OUT:D2.5, OUT:D3.5, OUT:D4.5, OUT:RN2.8
OUT:SEG_DPO: OUT:IC1.17, OUT:RN2.7
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

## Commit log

2019-07-13 added first functional modules to schematic
    [SAP-1.sch]
2019-07-13 Started first layout blocks of the board
    [SAP-1.brd]
2019-07-13 Added simulation of clock circuit
2019-07-13 added RAM module and MAR
    [SAP-1.brd, SAP-1.sch]
2019-07-13 added program counter
    [SAP-1.brd, SAP-1.sch]
2019-07-13 added output module
    [SAP-1.brd, SAP-1.sch]
2019-07-13 connected seperate modules
    [SAP-1.brd, SAP-1.sch]
2019-07-13 added instruction decoder module
    [SAP-1.brd, SAP-1.sch]
2019-07-13 added CPU status register
    [SAP-1.brd, SAP-1.sch]
2019-07-14 added current limiting resistors
    [SAP-1.brd, SAP-1.sch]
2019-07-14 added mouser part numbers
    [SAP-1.brd, SAP-1.sch]
2019-07-14 added BOM
    [BOM.xlsx, SAP-1.brd, SAP-1.sch]
2019-07-15 layed out components on board
    [SAP-1.brd, SAP-1.sch]
2019-07-15 replace most discrete resistors with networks
    [SAP-1.brd, SAP-1.sch]
2019-07-16 started routing of modules
    [SAP-1.brd, SAP-1.sch]
2019-07-17 routed seperate modules except power nets
    [SAP-1.brd, SAP-1.sch]
2019-07-18 added first routing pass
    [SAP-1.brd, SAP-1.sch]
2019-07-18 added mounting holes
    [SAP-1.brd, SAP-1.sch]
2019-07-18 rounded board outline
    [SAP-1.brd]
2019-07-18 first silkscreen cleanup pass and labeling
    [SAP-1.brd, SAP-1.sch]
2019-07-19 Second Silkscreen cleanup pass
    [SAP-1.brd, SAP-1.sch]
2019-08-04 updated attributes of resistor networks
    [SAP-1.brd, SAP-1.sch]
2019-08-04 added production gerbers
2019-08-04 updated BOM part numbers
    [BOM.xlsx]
2019-08-06 fixed minor issues with silkscreen
    [SAP-1.brd]
2019-08-07 switched to sphinx for documentation
2019-08-09 fixed silkscreen error
    [SAP-1.brd]
2019-08-10 lowered value of reset pull down
    [SAP-1.brd, SAP-1.sch]
2019-08-10 removed buffering of instruction register upper nibble
    [SAP-1.brd, SAP-1.sch]
2019-08-11 added simple assembler for SAP-1 ISA
2019-08-11 added section aboud writing programs and the assembler
2019-08-18 improved file loading for assembler finding files relative for the CWD
2020-01-14 added section about drive current of output decoder rto docs to address #3
2020-01-14 updated gerbers to reflect latest PCB changes, fixes #2
2020-01-14 fixed partnumber of CLK:IC7 (74LS06->74LLS04) to fix #1
    [BOM.xlsx, SAP-1.brd, SAP-1.sch]

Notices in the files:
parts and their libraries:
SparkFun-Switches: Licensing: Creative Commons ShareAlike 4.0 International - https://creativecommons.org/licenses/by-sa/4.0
